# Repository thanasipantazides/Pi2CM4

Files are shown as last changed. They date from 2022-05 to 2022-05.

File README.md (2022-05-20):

# Pi2CM4
An adapter board for the [Raspberry Pi Compute Module 4](https://datasheets.raspberrypi.com/cm4/cm4-datasheet.pdf) that has the footprint and I/O connectors of a Raspberry Pi 2/3/[4](https://datasheets.raspberrypi.com/rpi4/raspberry-pi-4-product-brief.pdf).

## WARNING: HAS NOT BEEN TESTED.
I will update when testing is done.

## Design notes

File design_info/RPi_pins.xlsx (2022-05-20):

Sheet: CM4_pins
Pin | Function
1 | GND
2 | GND
3 | Ethernet_Pair3_P
4 | Ethernet_Pair1_P
5 | Ethernet_Pair3_N
6 | Ethernet_Pair1_N
7 | GND
8 | GND
9 | Ethernet_Pair2_N
10 | Ethernet_Pair0_N
11 | Ethernet_Pair2_P
12 | Ethernet_Pair0_P
13 | GND
14 | GND
15 | Ethernet_nLED3
16 | Ethernet_SYNC_IN
17 | Ethernet_nLED2
18 | Ethernet_SYNC_OUT
19 | Ethernet_nLED1
20 | EEPROM_nWP
21 | Pi_nLED_Activity
22 | GND
23 | GND
24 | GPIO26
25 | GPIO21
26 | GPIO19
27 | GPIO20
28 | GPIO13
29 | GPIO16
30 | GPIO6
31 | GPIO12
32 | GND
33 | GND
34 | GPIO5
35 | ID_SC
36 | ID_SD
37 | GPIO7
38 | GPIO11
39 | GPIO8
40 | GPIO9
41 | GPIO25
42 | GND
43 | GND
44 | GPIO10
45 | GPIO24
46 | GPIO22
47 | GPIO23
48 | GPIO27
49 | GPIO18
50 | GPIO17
51 | GPIO15
52 | GND
53 | GND
54 | GPIO4
55 | GPIO14
56 | GPIO3
57 | SD_CLK
58 | GPIO2
59 | GND
60 | GND
61 | SD_DAT3
62 | SD_CMD
63 | SD_DAT0
64 | SD_DAT5
65 | GND
66 | GND
67 | SD_DAT1
68 | SD_DAT4
69 | SD_DAT2
70 | SD_DAT7
71 | GND
72 | SD_DAT6
73 | SD_VDD_Override
74 | GND
75 | SD_PWR_ON
76 | Reserved
77 | 5V_IN
78 | GPIO_VREF
79 | 5V_IN
80 | SCL0
81 | 5V_IN
82 | SDA0
83 | 5V_IN
84 | CM4_3.3V_OUT
85 | 5V_IN
86 | CM4_3.3V_OUT
87 | 5V_IN
88 | CM4_1.8V_OUT
89 | WL_nDisable
90 | CM4_1.8V_OUT
91 | BT_nDisable
92 | RUN_PG
93 | nRPIBOOT
94 | AnalogIP1
95 | Pi_LED_nPWR
96 | AnalogIP0
97 | Camera_GPIO
98 | GND
99 | GLOBAL_EN
100 | nEXTRST
101 | USB_OTG_ID
102 | PCIe_CLK_nREQ
103 | USB_N
104 | DNC
105 | USB_P
106 | DNC
107 | GND
108 | GND
109 | PCIe_nRST
110 | PCIe_CLK_P
111 | VDAC_COMP
112 | PCIe_CLK_N
113 | GND
114 | GND
115 | CAM1_D0_N
116 | PCIe_RX_P
117 | CAM1_D0_P
118 | PCIe_RX_N
119 | GND
120 | GND
121 | CAM1_D1_N
122 | PCIe_TX_P
123 | CAM1_D1_P
124 | PCIe_TX_N
125 | GND
126 | GND
127 | CAM1_C_N
128 | CAM0_D0_N
129 | CAM1_C_P
130 | CAM0_D0_P
131 | GND
132 | GND
133 | CAM1_D2_N
134 | CAM0_D1_N
135 | CAM1_D2_P
136 | CAM0_D1_P
137 | GND
138 | GND
139 | CAM1_D3_N
140 | CAM0_C_N
141 | CAM1_D3_P
142 | CAM0_C_P
143 | HDMI1_HOTPLUG
144 | GND
145 | HDMI1_SDA
146 | HDMI1_TX2_P
147 | HDMI1_SCL
148 | HDMI1_TX2_N
149 | HDMI1_CEC
150 | GND
151 | HDMI0_CEC
152 | HDMI1_TX1_P
153 | HDMI0_HOTPLUG
154 | HDMI1_TX1_N
155 | GND
156 | GND
157 | DSI0_D0_N
158 | HDMI1_TX0_P
159 | DSI0_D0_P
160 | HDMI1_TX0_N
161 | GND
162 | GND
163 | DSI0_D1_N
164 | HDMI1_CLK_P
165 | DSI0_D1_P
166 | HDMI1_CLK_N
167 | GND
168 | GND
169 | DSI0_C_N
170 | HDMI0_TX2_P
171 | DSI0_C_P
172 | HDMI0_TX2_N
173 | GND
174 | GND
175 | DSI1_D0_N
176 | HDMI0_TX1_P
177 | DSI1_D0_P
178 | HDMI0_TX1_N
179 | GND
180 | GND
181 | DSI1_D1_N
182 | HDMI0_TX0_P
183 | DSI1_D1_P
184 | HDMI0_tx0_N
185 | GND
186 | GND
187 | DSI1_C_N
188 | HDMI0_CLK_P
189 | DSI1_C_P
190 | HDMI0_CLK_N
191 | GND
192 | GND
193 | DSI1_D2_N
194 | DSI1_D3_N
195 | DSI1_D2_P
196 | DSI1_D3_P
197 | GND
198 | GND
199 | HDMI0_SDA
200 | HDMI0_SCL

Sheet: Pi4_pins
Pin | Function
1 | 3.3V_IN
2 | 5V_IN
3 | GPIO2
4 | 5V_IN
5 | GPIO3
6 | GND
7 | GPIO4
8 | GPIO14
9 | GND
10 | GPIO15
11 | GPIO17
12 | GPIO18
13 | GPIO27
14 | GND
15 | GPIO22
16 | GPIO23
17 | 3.3V_IN
18 | GPIO24
19 | GPIO10
20 | GND
21 | GPIO9
22 | GPIO25
23 | GPIO11
24 | GPIO8
25 | GND
26 | GPIO7
27 | ID_SD
28 | ID_SC
29 | GPIO5
30 | GND
31 | GPIO6
32 | GPIO12
33 | GPIO13
34 | GND
35 | GPIO19
36 | GPIO16
37 | GPIO26
38 | GPIO20
39 | GND
40 | GPIO21

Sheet: CM4_GPIOs
GPIO | Pull | Alt0 | Alt1 | Alt2 | Alt3 | Alt4 | Alt5

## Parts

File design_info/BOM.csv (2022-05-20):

Id | Designator | Package | Quantity | Designation | Supplier and ref
1 | Module1 | Raspberry-Pi-4-Compute-Module | 1 | ComputeModule4
2 | J11 | USB_Micro-B_EDAC_UCON00686 | 1 | USB_OTG
3 | R15,R7 | R_0402_1005Metric | 2 | 12K 1%
4 | J14,J6 | Molex_052610-1572_2x15-1MP_P1.0mm_Vertical | 2 | Conn_02x15_Counter_Clockwise
5 | R4,R3 | R_0402_1005Metric | 2 | 1k
6 | C4,C3 | C_0402_1005Metric | 2 | 27pF
7 | J2,J1 | HDMI_Micro-D_Molex_46765-1x01 | 2 | 0467651001
8 | C9,C20,C10,C11,C12,C8,C21,C7,C2 | C_0402_1005Metric | 9 | 100n
9 | R13,R12,R16,R14 | R_0402_1005Metric | 4 | 36K 1%
10 | R19,R23,R22 | R_0402_1005Metric | 3 | 4.7k
11 | U6 | MSOP-10_3x3mm_P0.5mm | 1 | FSUSB42MUX
12 | TP2,TP1 | TestPoint_Pad_2.0x2.0mm | 2 | TestPoint
13 | H4 | MountingHole_2.7mm_M2.5 | 1 | hole
14 | C18,C15,C5,C16,C17,C13,C6,C1,C19 | C_0805_2012Metric | 9 | 10u
15 | D4,D3 | D_SOD-123 | 2 | D_Zener
16 | U5 | TRJG0926HENL | 1 | MagJack-A70-112-331N126
17 | U8,U3,U4 | USON-10_2.5x1.0mm_P0.5mm | 3 | TPD4EUSB30
18 | Y1 | Crystal_SMD_2520-4Pin_2.5x2.0mm | 1 | Crystal_GND24_Small
19 | R18,R21,R20 | R_0402_1005Metric | 3 | 2
20 | H3,H2,H1 | MountingHole_2.7mm_M2.5 | 3 | MountingHole
21 | J12,J4 | MOLEX_USB_67298-4090 | 2 | 690-008-221-904
22 | J3 | PinHeader_1x02_P2.54mm_Vertical | 1 | Conn_01x02
23 | J13 | PinSocket_1x02_P2.54mm_Vertical | 1 | Conn_01x02
24 | C14 | C_1210_3225Metric | 1 | 100uF
25 | R2,R1,R11,R10 | R_0402_1005Metric | 4 | 2.2K 1%
26 | D1 | LED_0603_1608Metric | 1 | LED Green
27 | D2 | LED_0603_1608Metric | 1 | LED Red
28 | J7,J5 | PinSocket_2x02_P2.54mm_Vertical | 2 | Conn_02x02_Odd_Even
29 | U7 | QFN-36-1EP_6x6mm_P0.5mm_EP3.7x3.7mm | 1 | USB2514B-I/M2
30 | U1 | SOT-353_SC-70-5 | 1 | 74LVC1G07SE-7
31 | J9 | PinHeader_2x20_P2.54mm_Vertical | 1 | header
32 | U9 | SOT-23-6 | 1 | AP22653W6
33 | U11 | SOT-23 | 1 | RT9742SNGV
34 | R17 | R_0402_1005Metric | 1 | 15K 1%
35 | R8,R9 | R_0402_1005Metric | 2 | 470R
36 | D6,D5 | D_MELF | 2 | D
37 | U2 | SOT-23-5 | 1 | RT9742GGJ5
38 | R5,R6 | R_0402_1005Metric | 2 | nf
39 | U10 | SOT-23-5 | 1 | 74LVC1G04
40 | Q1 | PowerPAK_1212_Dual | 1 | Q_Dual_PMOS_S1G1S2G2D2D2D1D1
41 | J8 | SDCARD_MOLEX_503398-1892 | 1 | Micro_SD_Card_Det

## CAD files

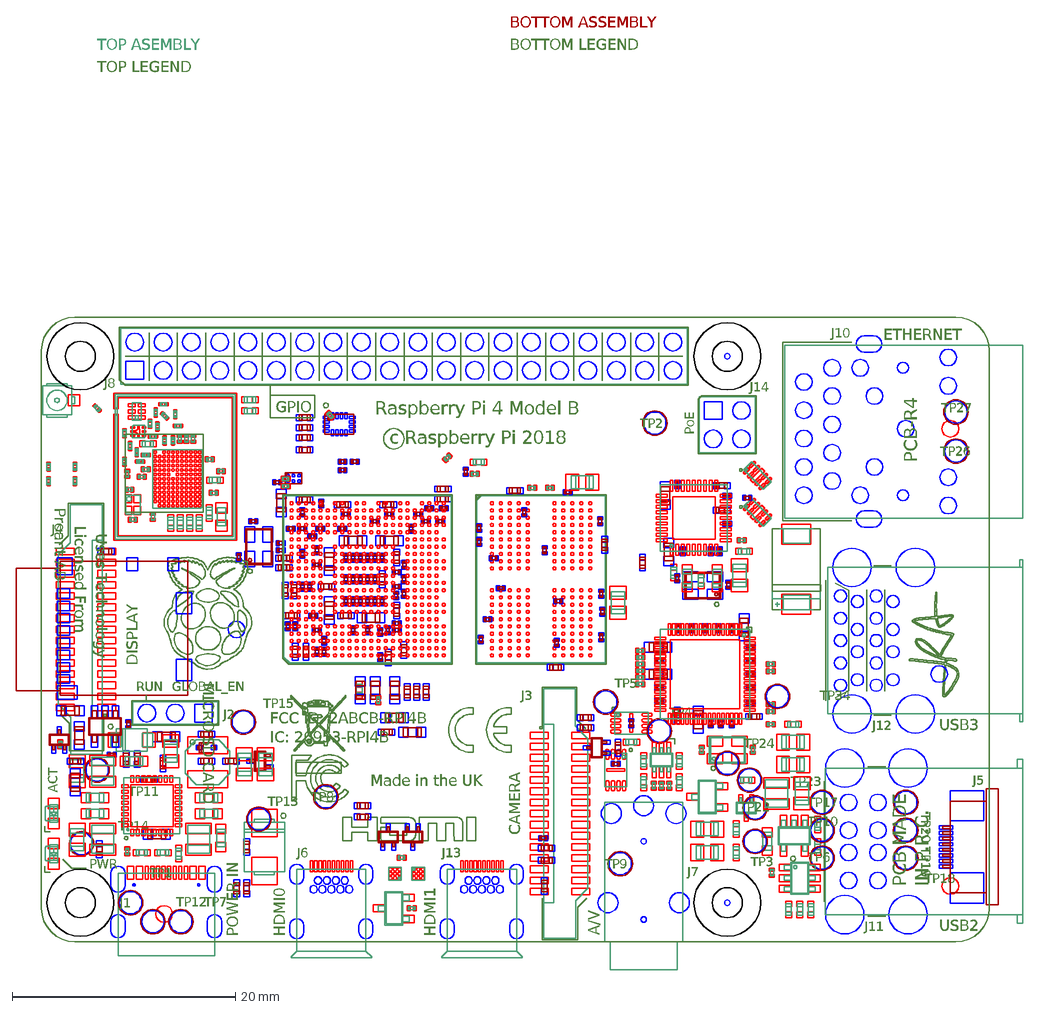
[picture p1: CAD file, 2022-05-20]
design_info/raspberry-pi-4-mechanical-drawing.dxf
TP20
TP19
TP18
TP17
TP10
TP6
TP5
TP34
TP15
TP14
TP13
TP11
TP8
TP7
TP24
TP23
TP22
TP12
TP9
TP4
TP3
TP2
TP1
TP27
TP26
J5
Made in the UK
IN P.R.C.
PCB MADE
IC: 20953-RPI4B
FCC ID: 2ABCB-RPI4B
PCB-R4
RUN
GLOBAL_EN
Proant AB
Licensed From
Uses Technology
MICRO SD CARD
GPIO
c Raspberry Pi 2018
Raspberry Pi 4 Model B
J2
J8
J14
J11
J12
J10
J7
J13
J3
J6
J1
J4
PoE
USB3
USB2
ETHERNET
A/V
DISPLAY
CAMERA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

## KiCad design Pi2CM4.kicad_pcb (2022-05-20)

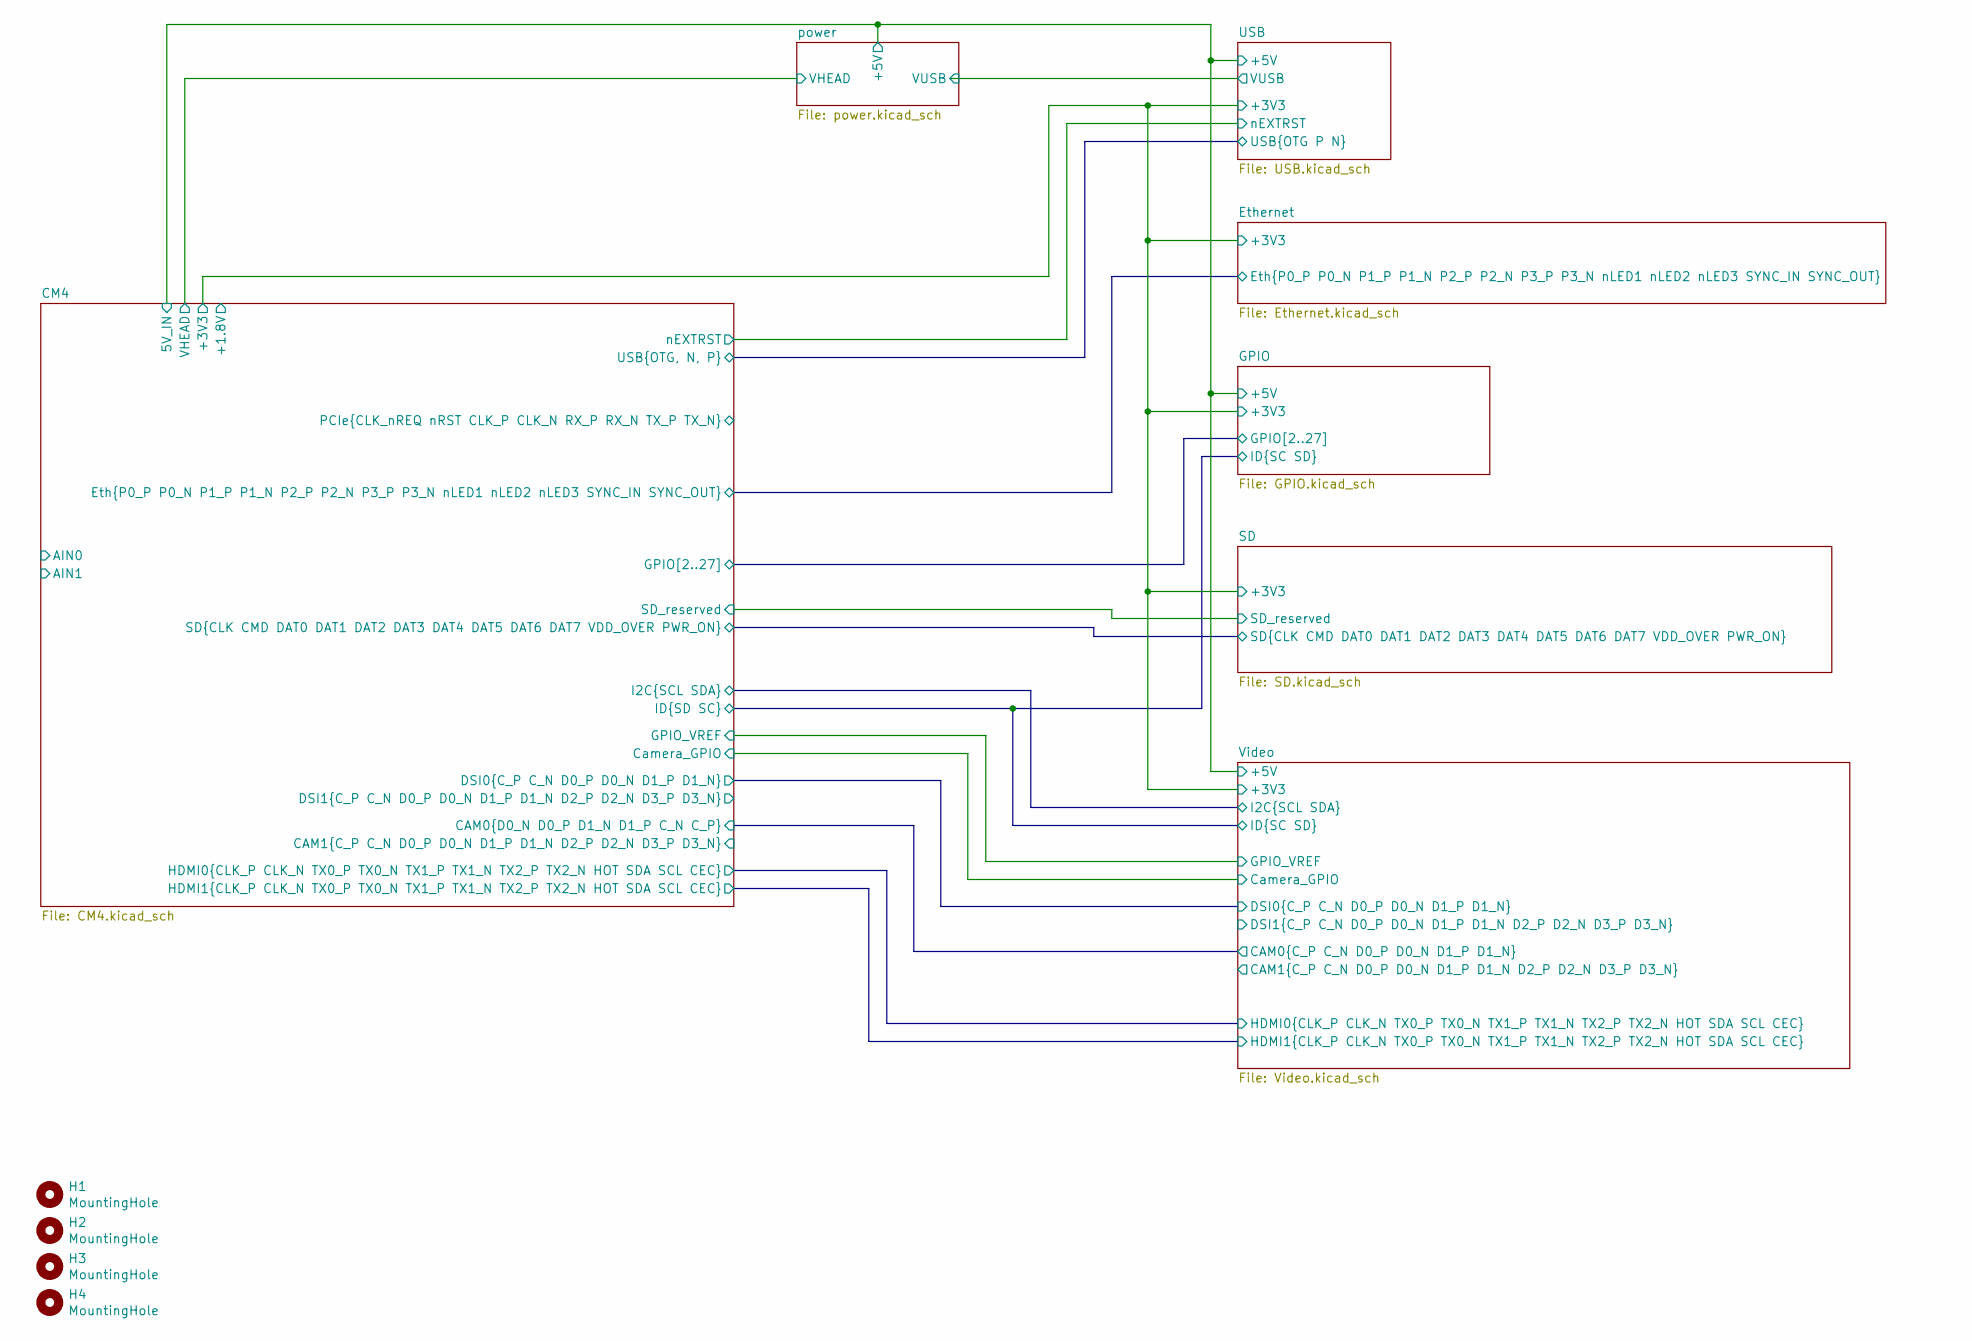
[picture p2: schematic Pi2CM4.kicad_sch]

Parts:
H1, H2, H3, H4: MountingHole; MountingHole_2.7mm_M2.5; Part Description M2.5 mounting hole

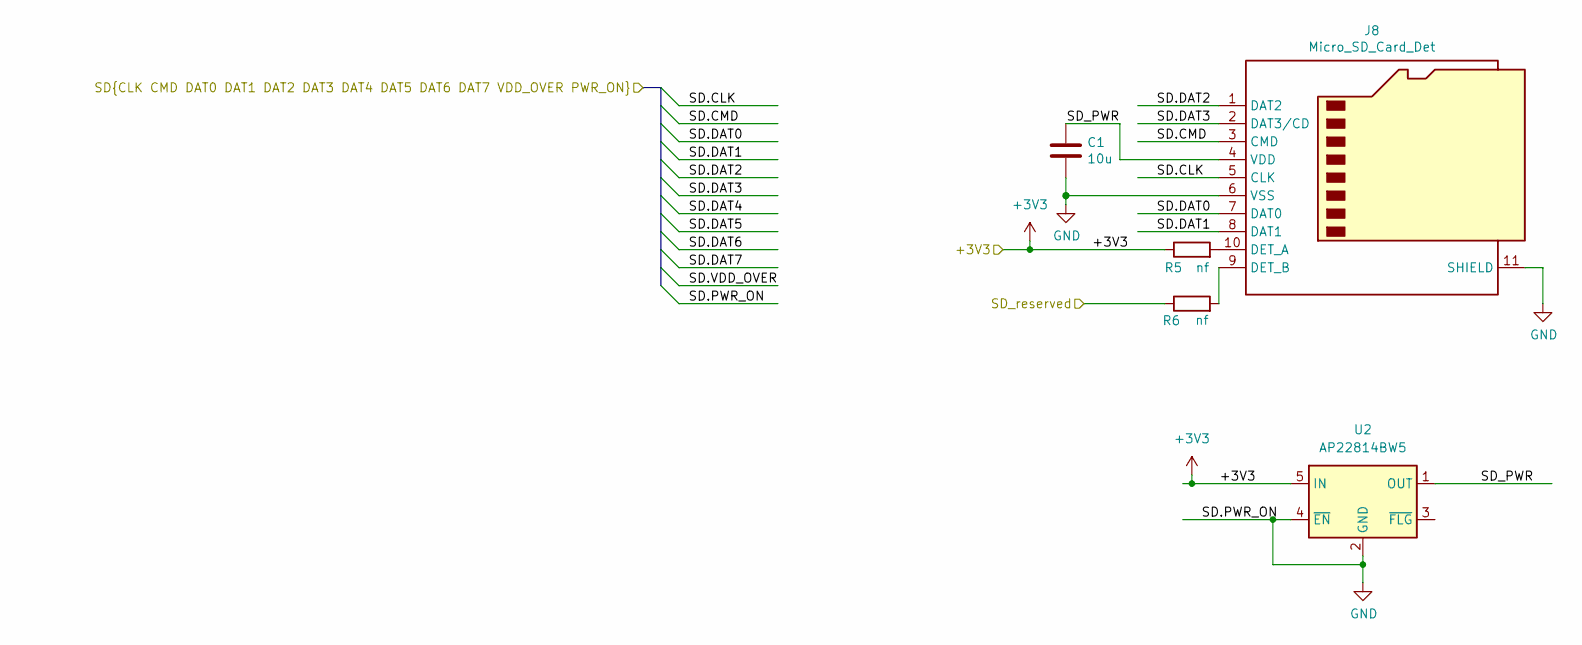
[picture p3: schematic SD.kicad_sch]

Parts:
C1: 10u; C_0805_2012Metric; Part Description 10uF 10% 10V Ceramic Capacitor X7R 0805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
J8: Micro_SD_Card_Det; SDCARD_MOLEX_503398-1892; Part Description 9 (8 + 1) Position Card Connector micro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
R5, R6: nf; R_0402_1005Metric; Part Description Resistor 1K M1005 1% 63mW
U2: AP22814BW5; SOT-23-5

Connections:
+3V3: R5.1, U2.5 (IN); also elsewhere on the board
/CM4/SD.CLK: J8.5 (CLK); also elsewhere on the board
/CM4/SD.CMD: J8.3 (CMD); also elsewhere on the board
/CM4/SD.DAT0: J8.7 (DAT0); also elsewhere on the board
/CM4/SD.DAT1: J8.8 (DAT1); also elsewhere on the board
/CM4/SD.DAT2: J8.1 (DAT2); also elsewhere on the board
/CM4/SD.DAT3: J8.2 (DAT3/CD); also elsewhere on the board
/CM4/SD_reserved: R6.1; also elsewhere on the board
/SD/SD_PWR: C1.1, J8.4 (VDD), U2.1 (OUT)
GND: C1.2, J8.6 (VSS), J8.11 (SHIELD), U2.2 (GND), U2.4 (~EN); also elsewhere on the board
unnamed: J8.9 (DET_B), R6.2
unnamed: J8.10 (DET_A), R5.2

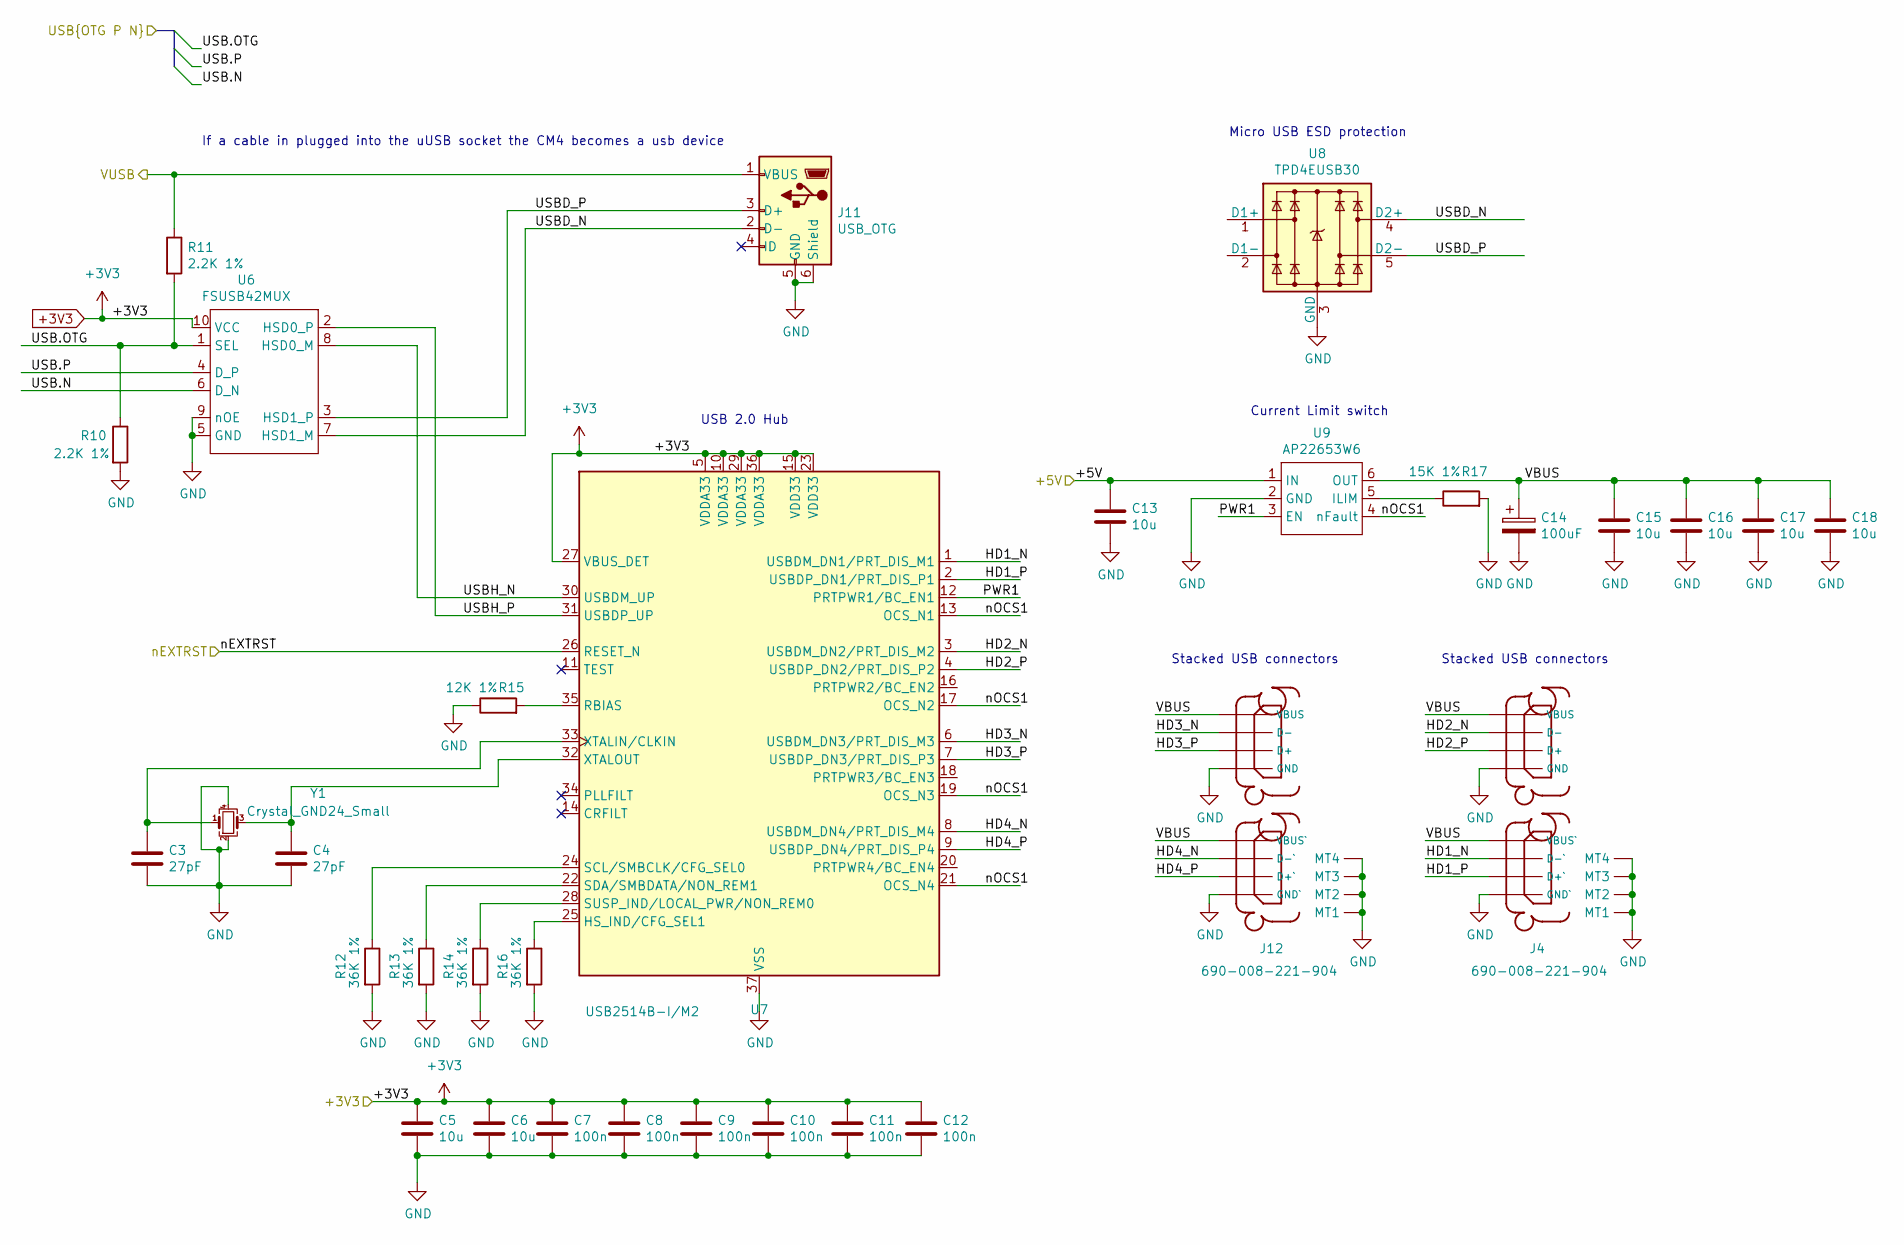
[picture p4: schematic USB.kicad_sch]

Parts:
C3, C4: 27pF; C_0402_1005Metric; Part Description 27pF 5% 50V Ceramic Capacitor C0G, NP0 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
C5, C6, C13, C15, C16, C17, C18: 10u; C_0805_2012Metric; Part Description 10uF 10% 10V Ceramic Capacitor X7R 0805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
C7, C8, C9, C10, C11, C12: 100n; C_0402_1005Metric; Part Description 0.1uF 10% 16V Ceramic Capacitor X7R 040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
C14: 100uF; C_1210_3225Metric; Part Description Capacitor, SP-Cap, 100u, 6.3V, 15mR ESR
J4, J12: 690-008-221-904; MOLEX_USB_67298-4090; Part Description USB-A (USB TYPE-A), Stacked Receptacle 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
J11: USB_OTG; USB_Micro-B_EDAC_UCON00686; Part Description USB - micro B USB 2.0 Receptacle Connec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
R10, R11: 2.2K 1%; R_0402_1005Metric; Part Description Resistor 2.2K M1005 1% 63mW
R12, R13, R14, R16: 36K 1%; R_0402_1005Metric; Part Description Resistor 36K M1005 1% 63mW
R15: 12K 1%; R_0402_1005Metric; Part Description Resistor 12K M1005 1% 63mW
R17: 15K 1%; R_0402_1005Metric; Part Description Resistor 15K M1005 1% 63mW
U6: FSUSB42MUX; Texas_R-PUQFN-N10; Part Description USB Switch IC 1 Channel 10-MSOP
U7: USB2514B-I/M2; QFN-36-1EP_6x6mm_P0.5mm_EP3.7x3.7mm; Part Description USB Hub Controller USB Interface 36-SQF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
U8: TPD4EUSB30; USON-10_2.5x1.0mm_P0.5mm; Part Description Quad TVS diode for high speed signals (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
U9: AP22653W6; SOT-23-6; Part Description Power Switch/Driver 1:1 P-Channel 2.1A 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
Y1: Crystal_GND24_Small; Crystal_SMD_2520-4Pin_2.5x2.0mm

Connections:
+3V3: C5.1, C6.1, C7.1, C8.1, C9.1, C10.1, C11.1, C12.1, U6.10 (VCC), U7.5 (VDDA33), U7.10 (VDDA33), U7.15 (VDD33), U7.23 (VDD33), U7.27 (VBUS_DET), U7.29 (VDDA33), U7.36 (VDDA33); also elsewhere on the board
+5V: C13.1, U9.1 (IN); also elsewhere on the board
/CM4/USB.N: U6.6 (D_N); also elsewhere on the board
/CM4/USB.OTG: R10.1, R11.2, U6.1 (SEL); also elsewhere on the board
/CM4/USB.P: U6.4 (D_P); also elsewhere on the board
/CM4/nEXTRST: U7.26 (RESET_N); also elsewhere on the board
/USB/HD1_N: J4.2 (D-`), U7.1 (USBDM_DN1/PRT_DIS_M1)
/USB/HD1_P: J4.3 (D+`), U7.2 (USBDP_DN1/PRT_DIS_P1)
/USB/HD2_N: J4.6 (D-), U7.3 (USBDM_DN2/PRT_DIS_M2)
/USB/HD2_P: J4.7 (D+), U7.4 (USBDP_DN2/PRT_DIS_P2)
/USB/HD3_N: J12.6 (D-), U7.6 (USBDM_DN3/PRT_DIS_M3)
/USB/HD3_P: J12.7 (D+), U7.7 (USBDP_DN3/PRT_DIS_P3)
/USB/HD4_N: J12.2 (D-`), U7.8 (USBDM_DN4/PRT_DIS_M4)
/USB/HD4_P: J12.3 (D+`), U7.9 (USBDP_DN4/PRT_DIS_P4)
/USB/PWR1: U7.12 (PRTPWR1/BC_EN1), U9.3 (EN)
/USB/USBD_N: J11.2 (D-), U6.7 (HSD1_M), U8.4 (D2+), U8.7
/USB/USBD_P: J11.3 (D+), U6.3 (HSD1_P), U8.5 (D2-), U8.6
/USB/USBH_N: U6.8 (HSD0_M), U7.30 (USBDM_UP)
/USB/USBH_P: U6.2 (HSD0_P), U7.31 (USBDP_UP)
/USB/VBUS: C14.1, C15.1, C16.1, C17.1, C18.1, J4.1 (VBUS`), J4.5 (VBUS), J12.1 (VBUS`), J12.5 (VBUS), U9.6 (OUT)
/USB/VUSB: J11.1 (VBUS), R11.1
/USB/nOCS1: U7.13 (OCS_N1), U7.17 (OCS_N2), U7.19 (OCS_N3), U7.21 (OCS_N4), U9.4 (nFault)
GND: C3.2, C4.2, C5.2, C6.2, C7.2, C8.2, C9.2, C10.2, C11.2, C12.2, C13.2, C14.2, C15.2, C16.2, C17.2, C18.2, J4.4 (GND`), J4.8 (GND), J4.MT1, J4.MT2, J4.MT3, J4.MT4, J11.5 (GND), J11.6 (Shield), J12.4 (GND`), J12.8 (GND), J12.MT1, J12.MT2, J12.MT3, J12.MT4, R10.2, R12.2, R13.2, R14.2, R15.1, R16.2, R17.2, U6.5 (GND), U6.9 (nOE), U7.37 (VSS), U8.3 (GND), U8.8 (GND), U9.2 (GND), Y1.2, Y1.4; also elsewhere on the board
unnamed: C3.1, U7.33 (XTALIN/CLKIN), Y1.1
unnamed: C4.1, U7.32 (XTALOUT), Y1.3
unnamed: R12.1, U7.24 (SCL/SMBCLK/CFG_SEL0)
unnamed: R13.1, U7.22 (SDA/SMBDATA/NON_REM1)
unnamed: R14.1, U7.28 (SUSP_IND/LOCAL_PWR/NON_REM0)
unnamed: R15.2, U7.35 (RBIAS)
unnamed: R16.1, U7.25 (HS_IND/CFG_SEL1)
unnamed: R17.1, U9.5 (ILIM)
unnamed: U8.1 (D1+), U8.10
unnamed: U8.2 (D1-), U8.9

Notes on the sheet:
Current Limit switch
Stacked USB connectors
Micro USB ESD protection
If a cable in plugged into the uUSB socket the CM4 becomes a usb device
USB 2.0 Hub

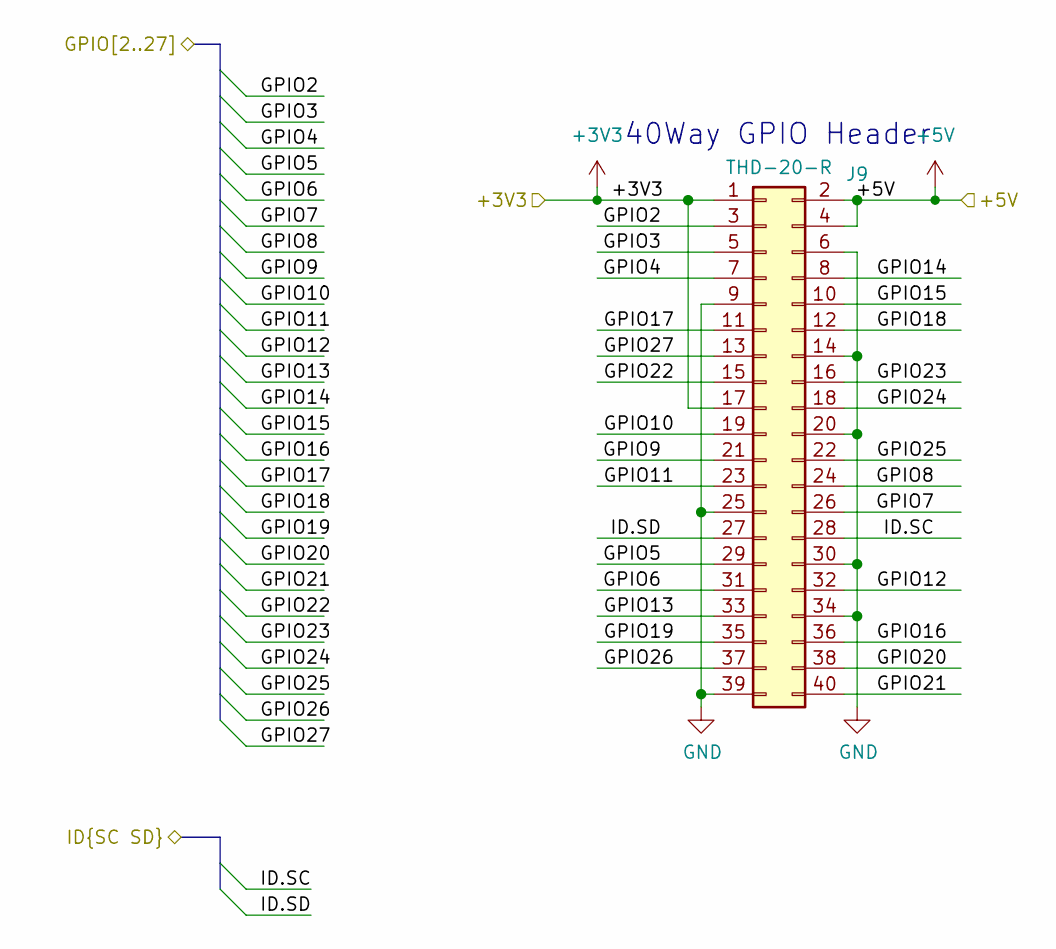
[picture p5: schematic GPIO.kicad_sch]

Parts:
J9: THD-20-R; PinHeader_2x20_P2.54mm_Vertical; Part Description PinHeader_2x20_P2.54mm_Vertical

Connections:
+3V3: J9.1, J9.17; also elsewhere on the board
+5V: J9.2, J9.4; also elsewhere on the board
/CM4/GPIO2: J9.3; also elsewhere on the board
/CM4/GPIO3: J9.5; also elsewhere on the board
/CM4/GPIO4: J9.7; also elsewhere on the board
/CM4/GPIO5: J9.29; also elsewhere on the board
/CM4/GPIO6: J9.31; also elsewhere on the board
/CM4/GPIO7: J9.26; also elsewhere on the board
/CM4/GPIO8: J9.24; also elsewhere on the board
/CM4/GPIO9: J9.21; also elsewhere on the board
/CM4/GPIO10: J9.19; also elsewhere on the board
/CM4/GPIO11: J9.23; also elsewhere on the board
/CM4/GPIO12: J9.32; also elsewhere on the board
/CM4/GPIO13: J9.33; also elsewhere on the board
/CM4/GPIO14: J9.8; also elsewhere on the board
/CM4/GPIO15: J9.10; also elsewhere on the board
/CM4/GPIO16: J9.36; also elsewhere on the board
/CM4/GPIO17: J9.11; also elsewhere on the board
/CM4/GPIO18: J9.12; also elsewhere on the board
/CM4/GPIO19: J9.35; also elsewhere on the board
/CM4/GPIO20: J9.38; also elsewhere on the board
/CM4/GPIO21: J9.40; also elsewhere on the board
/CM4/GPIO22: J9.15; also elsewhere on the board
/CM4/GPIO23: J9.16; also elsewhere on the board
/CM4/GPIO24: J9.18; also elsewhere on the board
/CM4/GPIO25: J9.22; also elsewhere on the board
/CM4/GPIO26: J9.37; also elsewhere on the board
/CM4/GPIO27: J9.13; also elsewhere on the board
/CM4/ID.SC: J9.28; also elsewhere on the board
/CM4/ID.SD: J9.27; also elsewhere on the board
GND: J9.6, J9.9, J9.14, J9.20, J9.25, J9.30, J9.34, J9.39; also elsewhere on the board

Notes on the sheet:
40Way GPIO Header

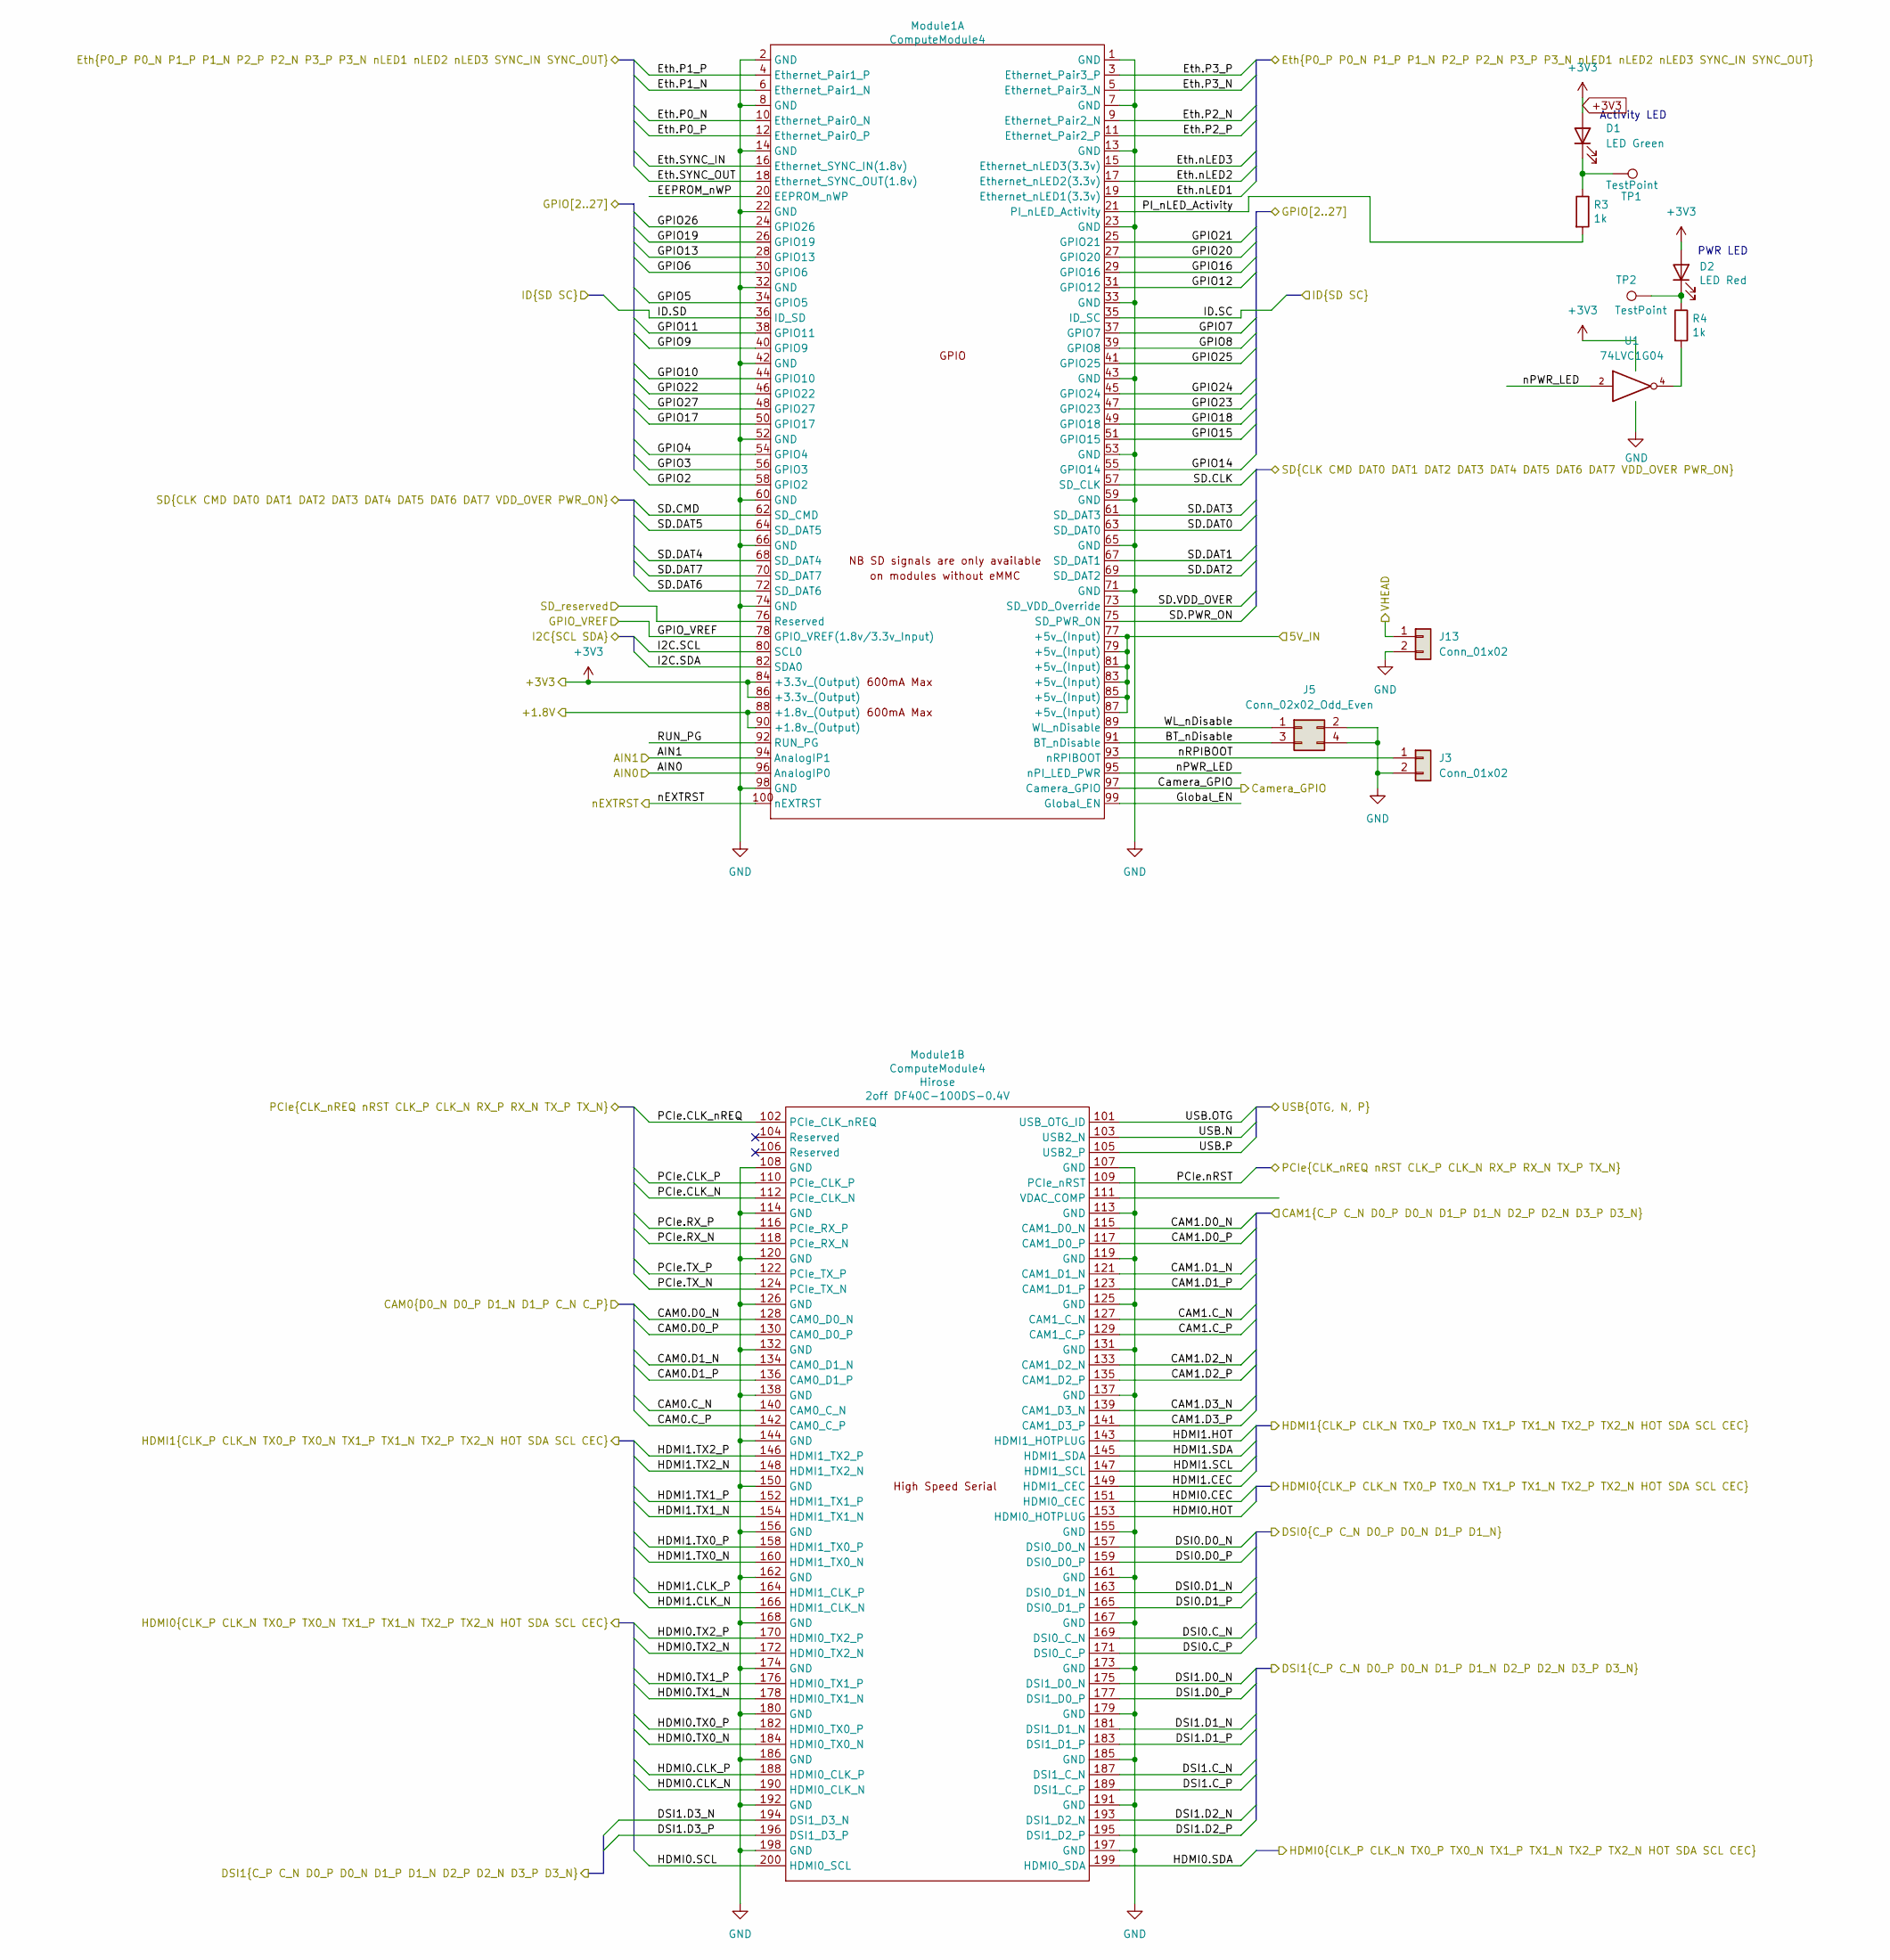
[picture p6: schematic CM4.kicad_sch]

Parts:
D1: LED Green; LED_0603_1608Metric; Part Description Green 572nm LED Indication - Discrete 2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
D2: LED Red; LED_0603_1608Metric; Part Description Red 620nm LED Indication - Discrete 2.2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
J3: Conn_01x02; PinHeader_1x02_P2.54mm_Vertical
J5: Conn_02x02_Odd_Even; PinSocket_2x02_P2.54mm_Vertical
J13: Conn_01x02; PinSocket_1x02_P2.54mm_Vertical
Module1: ComputeModule4; Raspberry-Pi-4-Compute-Module; Part Description 100 Position Connector Receptacle, Cent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
R3, R4: 1k; R_0402_1005Metric; Part Description Resistor 1K M1005 1% 63mW
TP1, TP2: TestPoint; TestPoint_Pad_2.0x2.0mm
U1: 74LVC1G04; SOT-23-5

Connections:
+3V3: D1.2 (A), D2.2 (A), Module1.84 (+3.3v_(Output)), Module1.86 (+3.3v_(Output)), U1.5 (VCC); also elsewhere on the board
+5V: Module1.77 (+5v_(Input)), Module1.79 (+5v_(Input)), Module1.81 (+5v_(Input)), Module1.83 (+5v_(Input)), Module1.85 (+5v_(Input)), Module1.87 (+5v_(Input)); also elsewhere on the board
/CM4/+1.8V: Module1.88 (+1.8v_(Output)), Module1.90 (+1.8v_(Output))
/CM4/AIN0: Module1.96 (AnalogIP0)
/CM4/AIN1: Module1.94 (AnalogIP1)
/CM4/BT_nDisable: J5.3, Module1.91 (BT_nDisable)
/CM4/CAM0.C_N: Module1.140 (CAM0_C_N); also elsewhere on the board
/CM4/CAM0.C_P: Module1.142 (CAM0_C_P); also elsewhere on the board
/CM4/CAM0.D0_N: Module1.128 (CAM0_D0_N); also elsewhere on the board
/CM4/CAM0.D0_P: Module1.130 (CAM0_D0_P); also elsewhere on the board
/CM4/CAM0.D1_N: Module1.134 (CAM0_D1_N); also elsewhere on the board
/CM4/CAM0.D1_P: Module1.136 (CAM0_D1_P); also elsewhere on the board
/CM4/CAM1.C_N: Module1.127 (CAM1_C_N)
/CM4/CAM1.C_P: Module1.129 (CAM1_C_P)
/CM4/CAM1.D0_N: Module1.115 (CAM1_D0_N)
/CM4/CAM1.D0_P: Module1.117 (CAM1_D0_P)
/CM4/CAM1.D1_N: Module1.121 (CAM1_D1_N)
/CM4/CAM1.D1_P: Module1.123 (CAM1_D1_P)
/CM4/CAM1.D2_N: Module1.133 (CAM1_D2_N)
/CM4/CAM1.D2_P: Module1.135 (CAM1_D2_P)
/CM4/CAM1.D3_N: Module1.139 (CAM1_D3_N)
/CM4/CAM1.D3_P: Module1.141 (CAM1_D3_P)
/CM4/Camera_GPIO: Module1.97 (Camera_GPIO); also elsewhere on the board
/CM4/DSI0.C_N: Module1.169 (DSI0_C_N); also elsewhere on the board
/CM4/DSI0.C_P: Module1.171 (DSI0_C_P); also elsewhere on the board
/CM4/DSI0.D0_N: Module1.157 (DSI0_D0_N); also elsewhere on the board
/CM4/DSI0.D0_P: Module1.159 (DSI0_D0_P); also elsewhere on the board
/CM4/DSI0.D1_N: Module1.163 (DSI0_D1_N); also elsewhere on the board
/CM4/DSI0.D1_P: Module1.165 (DSI0_D1_P); also elsewhere on the board
/CM4/DSI1.C_N: Module1.187 (DSI1_C_N)
/CM4/DSI1.C_P: Module1.189 (DSI1_C_P)
/CM4/DSI1.D0_N: Module1.175 (DSI1_D0_N)
/CM4/DSI1.D0_P: Module1.177 (DSI1_D0_P)
/CM4/DSI1.D1_N: Module1.181 (DSI1_D1_N)
/CM4/DSI1.D1_P: Module1.183 (DSI1_D1_P)
/CM4/DSI1.D2_N: Module1.193 (DSI1_D2_N)
/CM4/DSI1.D2_P: Module1.195 (DSI1_D2_P)
/CM4/DSI1.D3_N: Module1.194 (DSI1_D3_N)
/CM4/DSI1.D3_P: Module1.196 (DSI1_D3_P)
/CM4/EEPROM_nWP: Module1.20 (EEPROM_nWP)
/CM4/Eth.P0_N: Module1.10 (Ethernet_Pair0_N); also elsewhere on the board
/CM4/Eth.P0_P: Module1.12 (Ethernet_Pair0_P); also elsewhere on the board
/CM4/Eth.P1_N: Module1.6 (Ethernet_Pair1_N); also elsewhere on the board
/CM4/Eth.P1_P: Module1.4 (Ethernet_Pair1_P); also elsewhere on the board
/CM4/Eth.P2_N: Module1.9 (Ethernet_Pair2_N); also elsewhere on the board
/CM4/Eth.P2_P: Module1.11 (Ethernet_Pair2_P); also elsewhere on the board
/CM4/Eth.P3_N: Module1.5 (Ethernet_Pair3_N); also elsewhere on the board
/CM4/Eth.P3_P: Module1.3 (Ethernet_Pair3_P); also elsewhere on the board
/CM4/Eth.SYNC_IN: Module1.16 (Ethernet_SYNC_IN(1.8v))
/CM4/Eth.SYNC_OUT: Module1.18 (Ethernet_SYNC_OUT(1.8v))
/CM4/Eth.nLED1: Module1.19 (Ethernet_nLED1(3.3v))
/CM4/Eth.nLED2: Module1.17 (Ethernet_nLED2(3.3v)); also elsewhere on the board
/CM4/Eth.nLED3: Module1.15 (Ethernet_nLED3(3.3v)); also elsewhere on the board
/CM4/GPIO2: Module1.58 (GPIO2); also elsewhere on the board
/CM4/GPIO3: Module1.56 (GPIO3); also elsewhere on the board
/CM4/GPIO4: Module1.54 (GPIO4); also elsewhere on the board
/CM4/GPIO5: Module1.34 (GPIO5); also elsewhere on the board
/CM4/GPIO6: Module1.30 (GPIO6); also elsewhere on the board
/CM4/GPIO7: Module1.37 (GPIO7); also elsewhere on the board
/CM4/GPIO8: Module1.39 (GPIO8); also elsewhere on the board
/CM4/GPIO9: Module1.40 (GPIO9); also elsewhere on the board
/CM4/GPIO10: Module1.44 (GPIO10); also elsewhere on the board
/CM4/GPIO11: Module1.38 (GPIO11); also elsewhere on the board
/CM4/GPIO12: Module1.31 (GPIO12); also elsewhere on the board
/CM4/GPIO13: Module1.28 (GPIO13); also elsewhere on the board
/CM4/GPIO14: Module1.55 (GPIO14); also elsewhere on the board
/CM4/GPIO15: Module1.51 (GPIO15); also elsewhere on the board
/CM4/GPIO16: Module1.29 (GPIO16); also elsewhere on the board
/CM4/GPIO17: Module1.50 (GPIO17); also elsewhere on the board
/CM4/GPIO18: Module1.49 (GPIO18); also elsewhere on the board
/CM4/GPIO19: Module1.26 (GPIO19); also elsewhere on the board
/CM4/GPIO20: Module1.27 (GPIO20); also elsewhere on the board
/CM4/GPIO21: Module1.25 (GPIO21); also elsewhere on the board
/CM4/GPIO22: Module1.46 (GPIO22); also elsewhere on the board
/CM4/GPIO23: Module1.47 (GPIO23); also elsewhere on the board
/CM4/GPIO24: Module1.45 (GPIO24); also elsewhere on the board
/CM4/GPIO25: Module1.41 (GPIO25); also elsewhere on the board
/CM4/GPIO26: Module1.24 (GPIO26); also elsewhere on the board
/CM4/GPIO27: Module1.48 (GPIO27); also elsewhere on the board
/CM4/GPIO_VREF: Module1.78 (GPIO_VREF(1.8v/3.3v_Input)); also elsewhere on the board
/CM4/Global_EN: Module1.99 (Global_EN)
/CM4/HDMI0.CEC: Module1.151 (HDMI0_CEC); also elsewhere on the board
/CM4/HDMI0.CLK_N: Module1.190 (HDMI0_CLK_N); also elsewhere on the board
/CM4/HDMI0.CLK_P: Module1.188 (HDMI0_CLK_P); also elsewhere on the board
/CM4/HDMI0.HOT: Module1.153 (HDMI0_HOTPLUG); also elsewhere on the board
/CM4/HDMI0.SCL: Module1.200 (HDMI0_SCL); also elsewhere on the board
/CM4/HDMI0.SDA: Module1.199 (HDMI0_SDA); also elsewhere on the board
/CM4/HDMI0.TX0_N: Module1.184 (HDMI0_TX0_N); also elsewhere on the board
/CM4/HDMI0.TX0_P: Module1.182 (HDMI0_TX0_P); also elsewhere on the board
/CM4/HDMI0.TX1_N: Module1.178 (HDMI0_TX1_N); also elsewhere on the board
/CM4/HDMI0.TX1_P: Module1.176 (HDMI0_TX1_P); also elsewhere on the board
/CM4/HDMI0.TX2_N: Module1.172 (HDMI0_TX2_N); also elsewhere on the board
/CM4/HDMI0.TX2_P: Module1.170 (HDMI0_TX2_P); also elsewhere on the board
/CM4/HDMI1.CEC: Module1.149 (HDMI1_CEC); also elsewhere on the board
/CM4/HDMI1.CLK_N: Module1.166 (HDMI1_CLK_N); also elsewhere on the board
/CM4/HDMI1.CLK_P: Module1.164 (HDMI1_CLK_P); also elsewhere on the board
/CM4/HDMI1.HOT: Module1.143 (HDMI1_HOTPLUG); also elsewhere on the board
/CM4/HDMI1.SCL: Module1.147 (HDMI1_SCL); also elsewhere on the board
/CM4/HDMI1.SDA: Module1.145 (HDMI1_SDA); also elsewhere on the board
/CM4/HDMI1.TX0_N: Module1.160 (HDMI1_TX0_N); also elsewhere on the board
/CM4/HDMI1.TX0_P: Module1.158 (HDMI1_TX0_P); also elsewhere on the board
/CM4/HDMI1.TX1_N: Module1.154 (HDMI1_TX1_N); also elsewhere on the board
/CM4/HDMI1.TX1_P: Module1.152 (HDMI1_TX1_P); also elsewhere on the board
/CM4/HDMI1.TX2_N: Module1.148 (HDMI1_TX2_N); also elsewhere on the board
/CM4/HDMI1.TX2_P: Module1.146 (HDMI1_TX2_P); also elsewhere on the board
/CM4/I2C.SCL: Module1.80 (SCL0); also elsewhere on the board
/CM4/I2C.SDA: Module1.82 (SDA0); also elsewhere on the board
/CM4/ID.SC: Module1.35 (ID_SC); also elsewhere on the board
/CM4/ID.SD: Module1.36 (ID_SD); also elsewhere on the board
/CM4/PCIe.CLK_N: Module1.112 (PCIe_CLK_N)
/CM4/PCIe.CLK_P: Module1.110 (PCIe_CLK_P)
/CM4/PCIe.CLK_nREQ: Module1.102 (PCIe_CLK_nREQ)
/CM4/PCIe.RX_N: Module1.118 (PCIe_RX_N)
/CM4/PCIe.RX_P: Module1.116 (PCIe_RX_P)
/CM4/PCIe.TX_N: Module1.124 (PCIe_TX_N)
/CM4/PCIe.TX_P: Module1.122 (PCIe_TX_P)
/CM4/PCIe.nRST: Module1.109 (PCIe_nRST)
/CM4/PI_nLED_Activity: Module1.21 (PI_nLED_Activity), R3.2
/CM4/RUN_PG: Module1.92 (RUN_PG)
/CM4/SD.CLK: Module1.57 (SD_CLK); also elsewhere on the board
/CM4/SD.CMD: Module1.62 (SD_CMD); also elsewhere on the board
/CM4/SD.DAT0: Module1.63 (SD_DAT0); also elsewhere on the board
/CM4/SD.DAT1: Module1.67 (SD_DAT1); also elsewhere on the board
/CM4/SD.DAT2: Module1.69 (SD_DAT2); also elsewhere on the board
/CM4/SD.DAT3: Module1.61 (SD_DAT3); also elsewhere on the board
/CM4/SD.DAT4: Module1.68 (SD_DAT4)
/CM4/SD.DAT5: Module1.64 (SD_DAT5)
/CM4/SD.DAT6: Module1.72 (SD_DAT6)
/CM4/SD.DAT7: Module1.70 (SD_DAT7)
/CM4/SD.VDD_OVER: Module1.73 (SD_VDD_Override)
/CM4/SD_reserved: Module1.76 (Reserved); also elsewhere on the board
/CM4/USB.N: Module1.103 (USB2_N); also elsewhere on the board
/CM4/USB.OTG: Module1.101 (USB_OTG_ID); also elsewhere on the board
/CM4/USB.P: Module1.105 (USB2_P); also elsewhere on the board
/CM4/VHEAD: J13.1; also elsewhere on the board
/CM4/WL_nDisable: J5.1, Module1.89 (WL_nDisable)
/CM4/nEXTRST: Module1.100 (nEXTRST); also elsewhere on the board
/CM4/nPWR_LED: Module1.95 (nPI_LED_PWR), U1.2
/CM4/nRPIBOOT: J3.1, Module1.93 (nRPIBOOT)
GND: J3.2, J5.2, J5.4, J13.2, Module1.1 (GND), Module1.2 (GND), Module1.7 (GND), Module1.8 (GND), Module1.13 (GND), Module1.14 (GND), Module1.22 (GND), Module1.23 (GND), Module1.32 (GND), Module1.33 (GND), Module1.42 (GND), Module1.43 (GND), Module1.52 (GND), Module1.53 (GND), Module1.59 (GND), Module1.60 (GND), Module1.65 (GND), Module1.66 (GND), Module1.71 (GND), Module1.74 (GND), Module1.75 (SD_PWR_ON), Module1.98 (GND), Module1.107 (GND), Module1.108 (GND), Module1.113 (GND), Module1.114 (GND), Module1.119 (GND), Module1.120 (GND), Module1.125 (GND), Module1.126 (GND), Module1.131 (GND), Module1.132 (GND), Module1.137 (GND), Module1.138 (GND), Module1.144 (GND), Module1.150 (GND), Module1.155 (GND), Module1.156 (GND), Module1.161 (GND), Module1.162 (GND), Module1.167 (GND), Module1.168 (GND), Module1.173 (GND), Module1.174 (GND), Module1.179 (GND), Module1.180 (GND), Module1.185 (GND), Module1.186 (GND), Module1.191 (GND), Module1.192 (GND), Module1.197 (GND), Module1.198 (GND), U1.3 (GND); also elsewhere on the board
unnamed: D1.1 (K), R3.1, TP1.1
unnamed: D2.1 (K), R4.1, TP2.1
unnamed: R4.2, U1.4

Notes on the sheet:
PWR LED
Activity LED

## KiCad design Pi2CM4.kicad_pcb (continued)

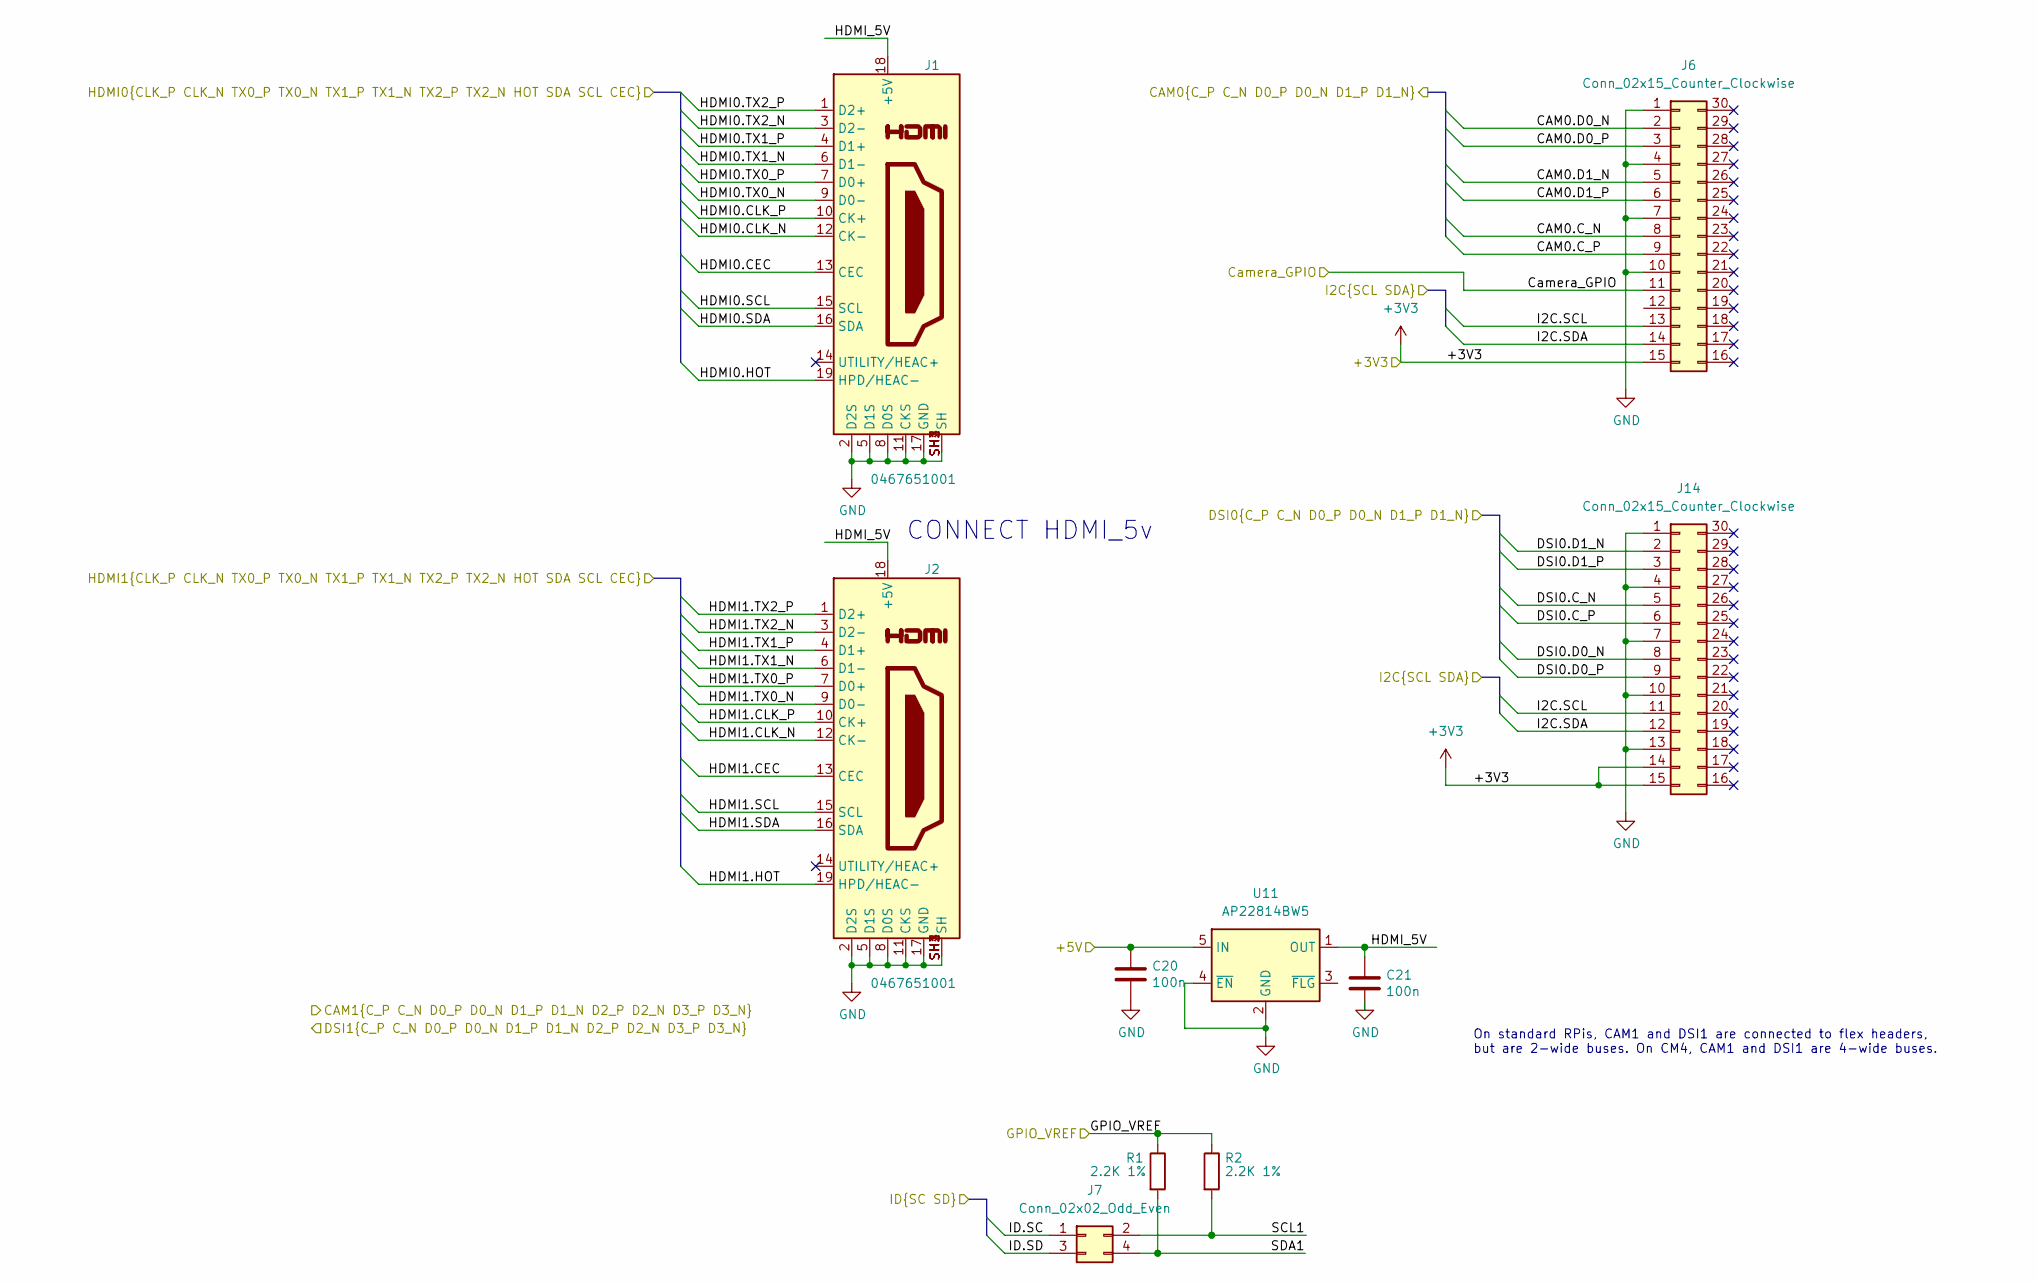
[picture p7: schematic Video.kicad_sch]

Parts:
C20, C21: 100n; C_0402_1005Metric; Part Description 0.1uF 10% 16V Ceramic Capacitor X7R 040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
J1, J2: 0467651001; HDMI_Micro-D_Molex_46765-1x01; Part Description HDMI Connector, Right Angle, 19 Contact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
J6, J14: Conn_02x15_Counter_Clockwise; Molex_052610-1572_2x15-1MP_P1.0mm_Vertical
J7: Conn_02x02_Odd_Even; PinSocket_2x02_P2.54mm_Vertical
R1, R2: 2.2K 1%; R_0402_1005Metric; Part Description Resistor 2.2K M1005 1% 63mW
U11: AP22814BW5; SOT-23-5

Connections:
+3V3: J6.15, J14.14, J14.15; also elsewhere on the board
+5V: C20.1, U11.5 (IN); also elsewhere on the board
/CM4/CAM0.C_N: J6.8; also elsewhere on the board
/CM4/CAM0.C_P: J6.9; also elsewhere on the board
/CM4/CAM0.D0_N: J6.2; also elsewhere on the board
/CM4/CAM0.D0_P: J6.3; also elsewhere on the board
/CM4/CAM0.D1_N: J6.5; also elsewhere on the board
/CM4/CAM0.D1_P: J6.6; also elsewhere on the board
/CM4/Camera_GPIO: J6.11; also elsewhere on the board
/CM4/DSI0.C_N: J14.5; also elsewhere on the board
/CM4/DSI0.C_P: J14.6; also elsewhere on the board
/CM4/DSI0.D0_N: J14.8; also elsewhere on the board
/CM4/DSI0.D0_P: J14.9; also elsewhere on the board
/CM4/DSI0.D1_N: J14.2; also elsewhere on the board
/CM4/DSI0.D1_P: J14.3; also elsewhere on the board
/CM4/GPIO_VREF: R1.1, R2.1; also elsewhere on the board
/CM4/HDMI0.CEC: J1.13 (CEC); also elsewhere on the board
/CM4/HDMI0.CLK_N: J1.12 (CK-); also elsewhere on the board
/CM4/HDMI0.CLK_P: J1.10 (CK+); also elsewhere on the board
/CM4/HDMI0.HOT: J1.19 (HPD/HEAC-); also elsewhere on the board
/CM4/HDMI0.SCL: J1.15 (SCL); also elsewhere on the board
/CM4/HDMI0.SDA: J1.16 (SDA); also elsewhere on the board
/CM4/HDMI0.TX0_N: J1.9 (D0-); also elsewhere on the board
/CM4/HDMI0.TX0_P: J1.7 (D0+); also elsewhere on the board
/CM4/HDMI0.TX1_N: J1.6 (D1-); also elsewhere on the board
/CM4/HDMI0.TX1_P: J1.4 (D1+); also elsewhere on the board
/CM4/HDMI0.TX2_N: J1.3 (D2-); also elsewhere on the board
/CM4/HDMI0.TX2_P: J1.1 (D2+); also elsewhere on the board
/CM4/HDMI1.CEC: J2.13 (CEC); also elsewhere on the board
/CM4/HDMI1.CLK_N: J2.12 (CK-); also elsewhere on the board
/CM4/HDMI1.CLK_P: J2.10 (CK+); also elsewhere on the board
/CM4/HDMI1.HOT: J2.19 (HPD/HEAC-); also elsewhere on the board
/CM4/HDMI1.SCL: J2.15 (SCL); also elsewhere on the board
/CM4/HDMI1.SDA: J2.16 (SDA); also elsewhere on the board
/CM4/HDMI1.TX0_N: J2.9 (D0-); also elsewhere on the board
/CM4/HDMI1.TX0_P: J2.7 (D0+); also elsewhere on the board
/CM4/HDMI1.TX1_N: J2.6 (D1-); also elsewhere on the board
/CM4/HDMI1.TX1_P: J2.4 (D1+); also elsewhere on the board
/CM4/HDMI1.TX2_N: J2.3 (D2-); also elsewhere on the board
/CM4/HDMI1.TX2_P: J2.1 (D2+); also elsewhere on the board
/CM4/I2C.SCL: J6.13, J14.11; also elsewhere on the board
/CM4/I2C.SDA: J6.14, J14.12; also elsewhere on the board
/CM4/ID.SC: J7.1; also elsewhere on the board
/CM4/ID.SD: J7.3; also elsewhere on the board
/Video/HDMI_5V: C21.1, J1.18 (+5V), J2.18 (+5V), U11.1 (OUT)
/Video/SCL1: J7.2, R2.2
/Video/SDA1: J7.4, R1.2
GND: C20.2, C21.2, J1.2 (D2S), J1.5 (D1S), J1.8 (D0S), J1.11 (CKS), J1.17 (GND), J1.SH1 (SH), J1.SH2 (SH), J1.SH3 (SH), J1.SH4 (SH), J2.2 (D2S), J2.5 (D1S), J2.8 (D0S), J2.11 (CKS), J2.17 (GND), J2.SH1 (SH), J2.SH2 (SH), J2.SH3 (SH), J2.SH4 (SH), J6.1, J6.4, J6.7, J6.10, J14.1, J14.4, J14.7, J14.10, J14.13, U11.2 (GND), U11.4 (~EN); also elsewhere on the board

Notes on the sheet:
CONNECT HDMI_5v
On standard RPis, CAM1 and DSI1 are connected to flex headers, but are 2-wide buses. On CM4, CAM1 and DSI1 are 4-wide buses.

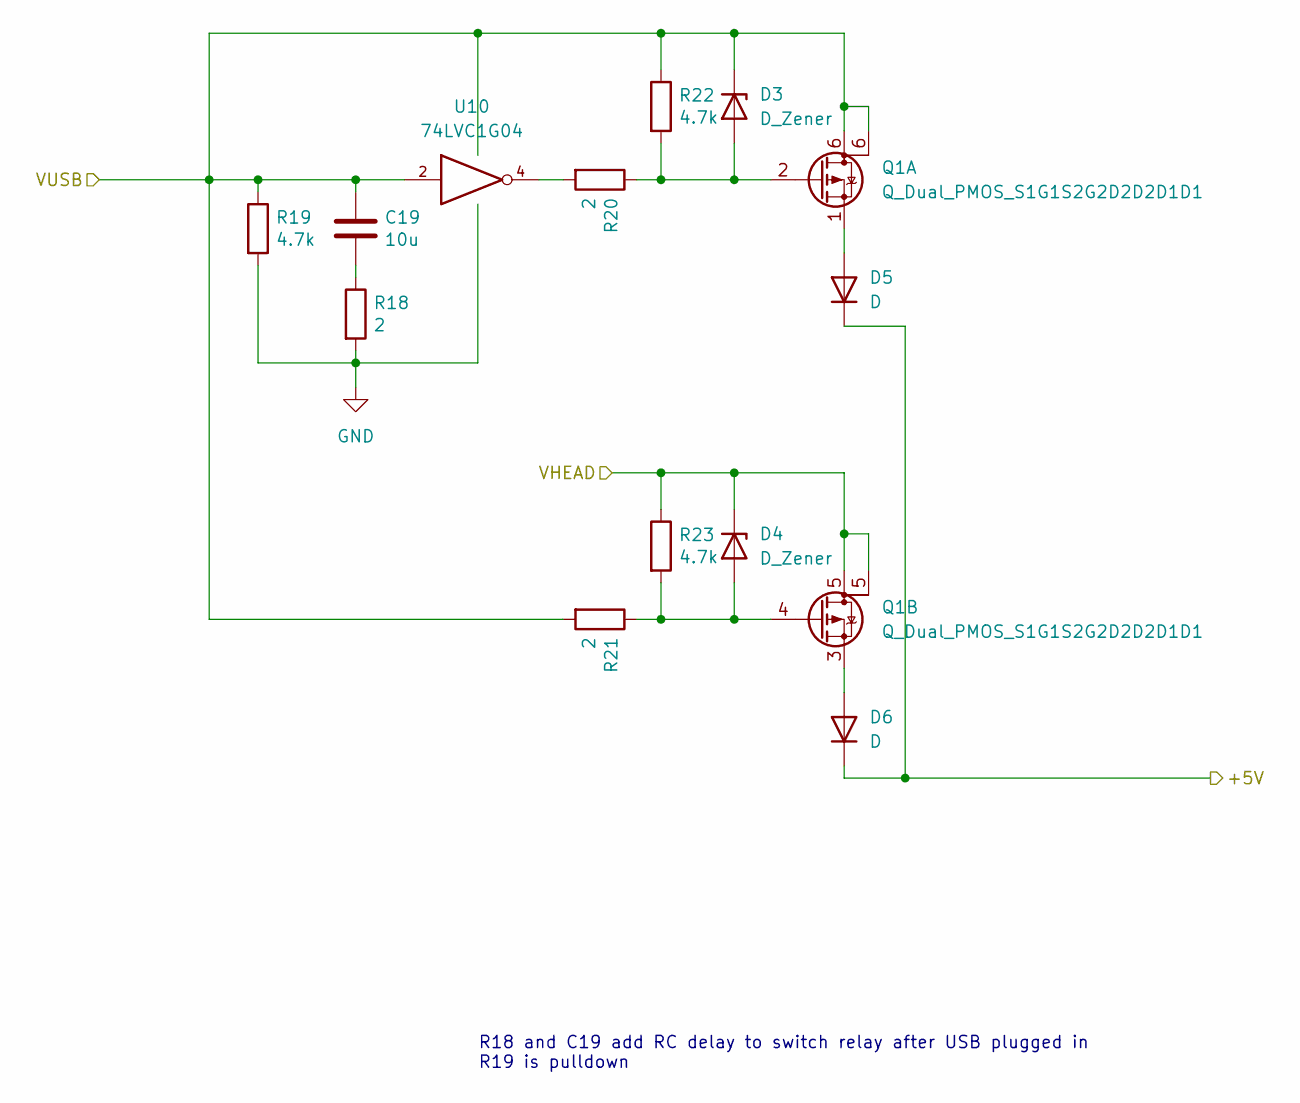
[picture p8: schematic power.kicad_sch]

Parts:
C19: 10u; C_0805_2012Metric; Part Description 10uF 10% 10V Ceramic Capacitor X7R 0805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
D3, D4: D_Zener; D_SOD-123
D5, D6: D; D_MELF
Q1: Q_Dual_PMOS_S1G1S2G2D2D2D1D1; PowerPAK_1212_Dual
R18, R20, R21: 2; R_2010_5025Metric; Part Description Resistor 1K M1005 1% 63mW
R19, R22, R23: 4.7k; R_0402_1005Metric; Part Description Resistor 1K M1005 1% 63mW
U10: 74LVC1G04; SOT-23-5

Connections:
+5V: D5.1 (K), D6.1 (K); also elsewhere on the board
/CM4/VHEAD: D4.1 (K), Q1.5 (D), R23.1; also elsewhere on the board
GND: R18.2, R19.2, U10.3 (GND); also elsewhere on the board
unnamed: C19.2, R18.1
unnamed: D3.2 (A), Q1.2 (G), R20.1, R22.2
unnamed: D4.2 (A), Q1.4 (G), R21.1, R23.2
unnamed: D5.2 (A), Q1.1 (S)
unnamed: D6.2 (A), Q1.3 (S)
unnamed: R20.2, U10.4
VCC: C19.1, D3.1 (K), Q1.6 (G), R19.1, R21.2, R22.1, U10.2, U10.5 (VCC)

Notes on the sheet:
R18 and C19 add RC delay to switch relay after USB plugged in R19 is pulldown

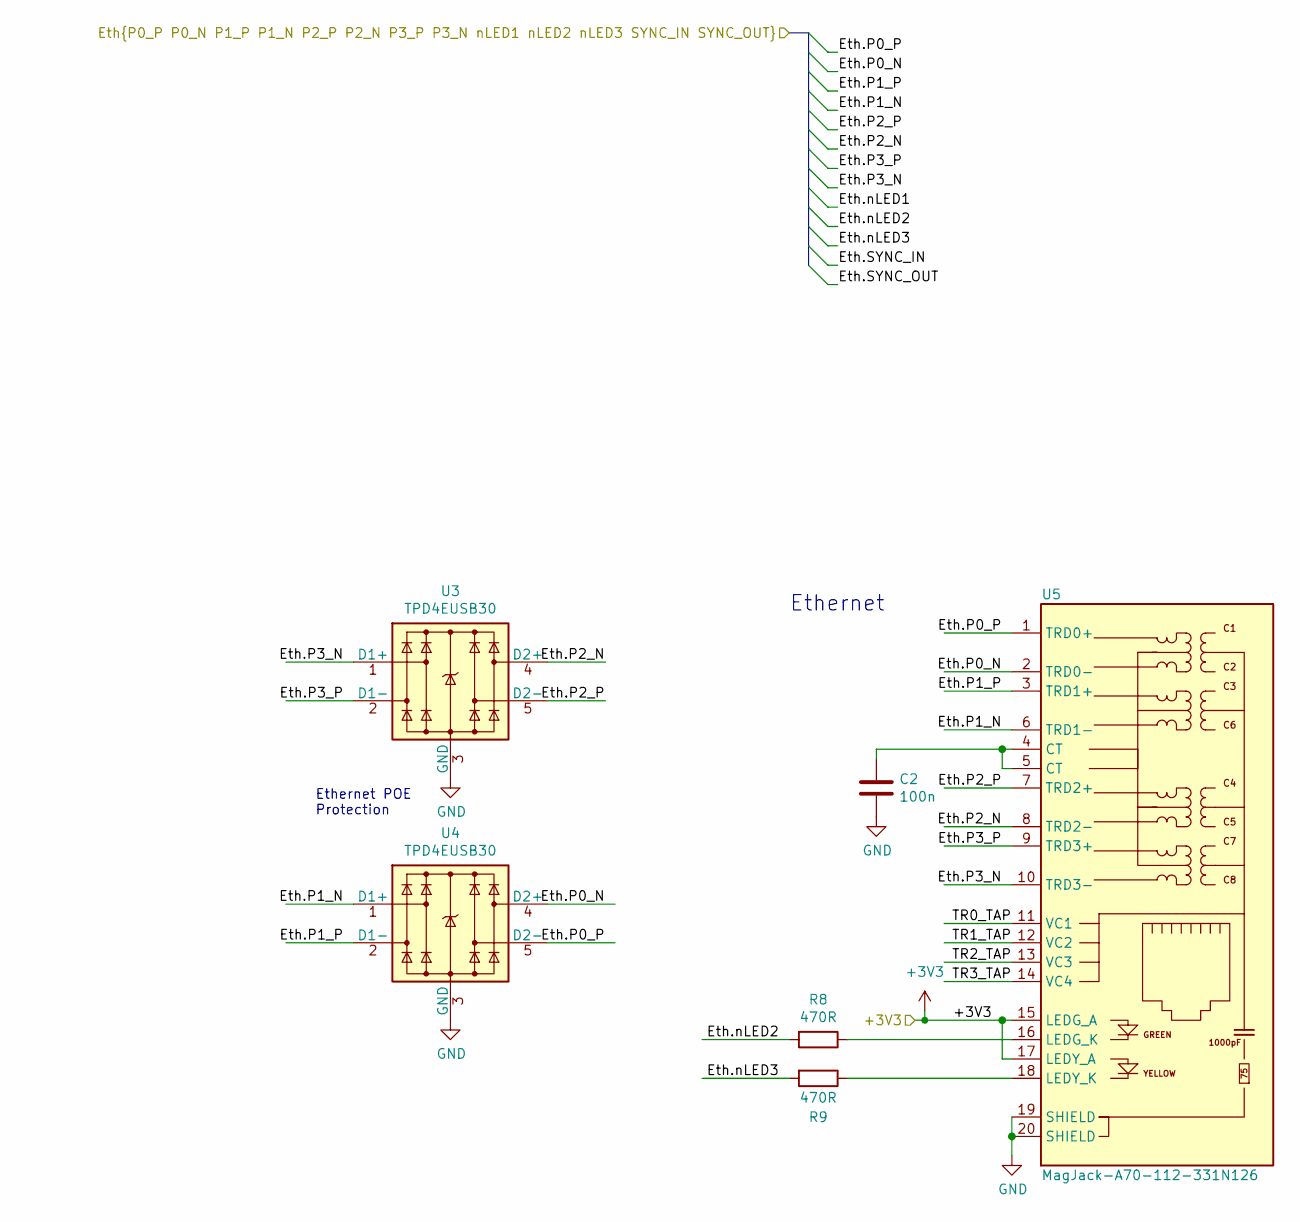
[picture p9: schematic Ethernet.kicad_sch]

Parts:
C2: 100n; C_0402_1005Metric; Part Description 0.1uF 10% 16V Ceramic Capacitor X7R 040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
R8, R9: 470R; R_0402_1005Metric; Part Description Resistor 470R M1005 1% 63mW
U3, U4: TPD4EUSB30; USON-10_2.5x1.0mm_P0.5mm; Part Description Quad TVS diode for high speed signals (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
U5: MagJack-A70-112-331N126; TRJG0926HENL; Part Description Gigabit Ethernet Magjack

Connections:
+3V3: U5.15 (LEDG_A), U5.17 (LEDY_A); also elsewhere on the board
/CM4/Eth.P0_N: U4.4 (D2+), U4.7, U5.2 (TRD0-); also elsewhere on the board
/CM4/Eth.P0_P: U4.5 (D2-), U4.6, U5.1 (TRD0+); also elsewhere on the board
/CM4/Eth.P1_N: U4.1 (D1+), U4.10, U5.6 (TRD1-); also elsewhere on the board
/CM4/Eth.P1_P: U4.2 (D1-), U4.9, U5.3 (TRD1+); also elsewhere on the board
/CM4/Eth.P2_N: U3.4 (D2+), U3.7, U5.8 (TRD2-); also elsewhere on the board
/CM4/Eth.P2_P: U3.5 (D2-), U3.6, U5.7 (TRD2+); also elsewhere on the board
/CM4/Eth.P3_N: U3.1 (D1+), U3.10, U5.10 (TRD3-); also elsewhere on the board
/CM4/Eth.P3_P: U3.2 (D1-), U3.9, U5.9 (TRD3+); also elsewhere on the board
/CM4/Eth.nLED2: R8.2; also elsewhere on the board
/CM4/Eth.nLED3: R9.2; also elsewhere on the board
/Ethernet/TR0_TAP: U5.11 (VC1)
/Ethernet/TR1_TAP: U5.12 (VC2)
/Ethernet/TR2_TAP: U5.13 (VC3)
/Ethernet/TR3_TAP: U5.14 (VC4)
GND: C2.2, U3.3 (GND), U3.8 (GND), U4.3 (GND), U4.8 (GND), U5.19 (SHIELD), U5.20 (SHIELD); also elsewhere on the board
unnamed: C2.1, U5.4 (CT), U5.5 (CT)
unnamed: R8.1, U5.16 (LEDG_K)
unnamed: R9.1, U5.18 (LEDY_K)

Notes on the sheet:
Ethernet
Ethernet POE Protection

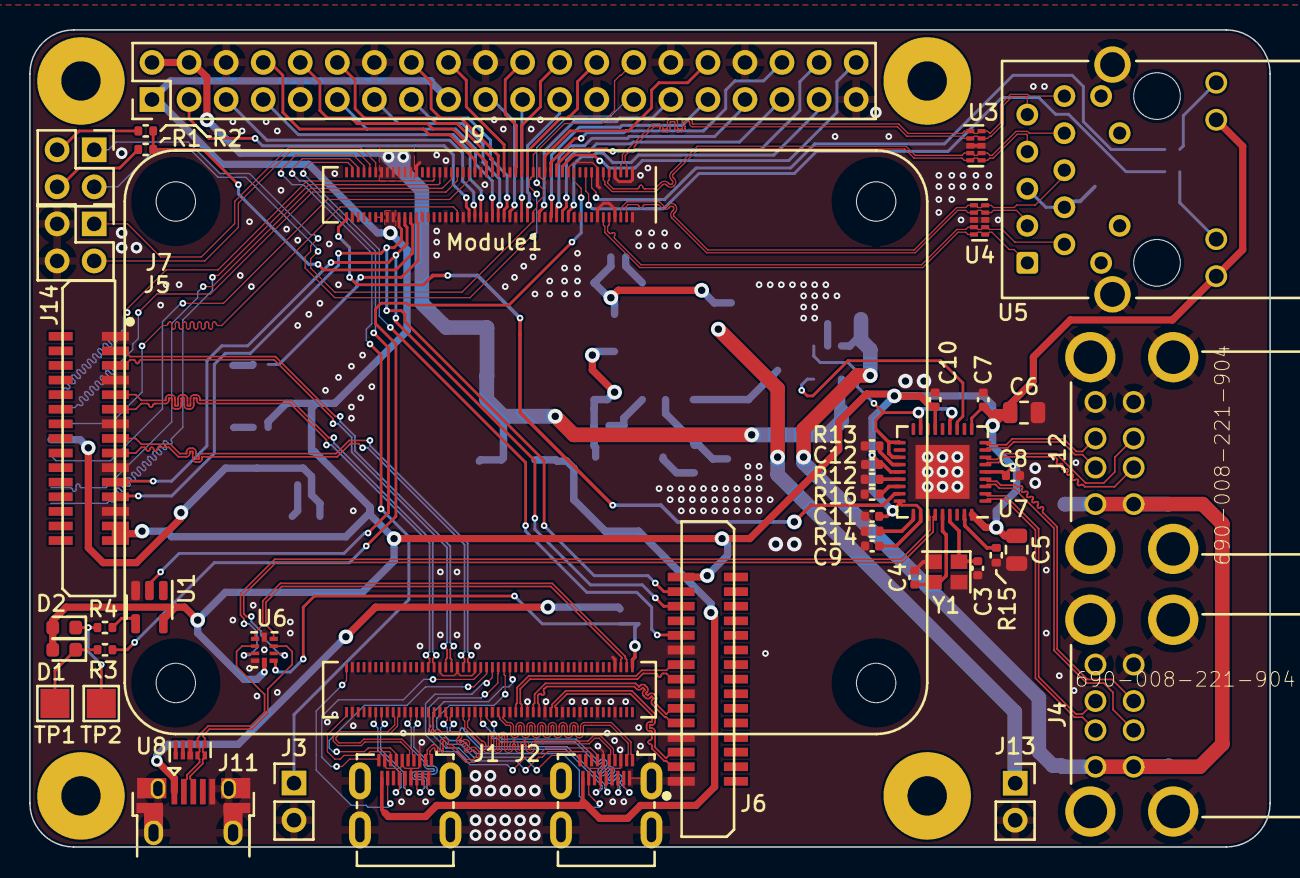
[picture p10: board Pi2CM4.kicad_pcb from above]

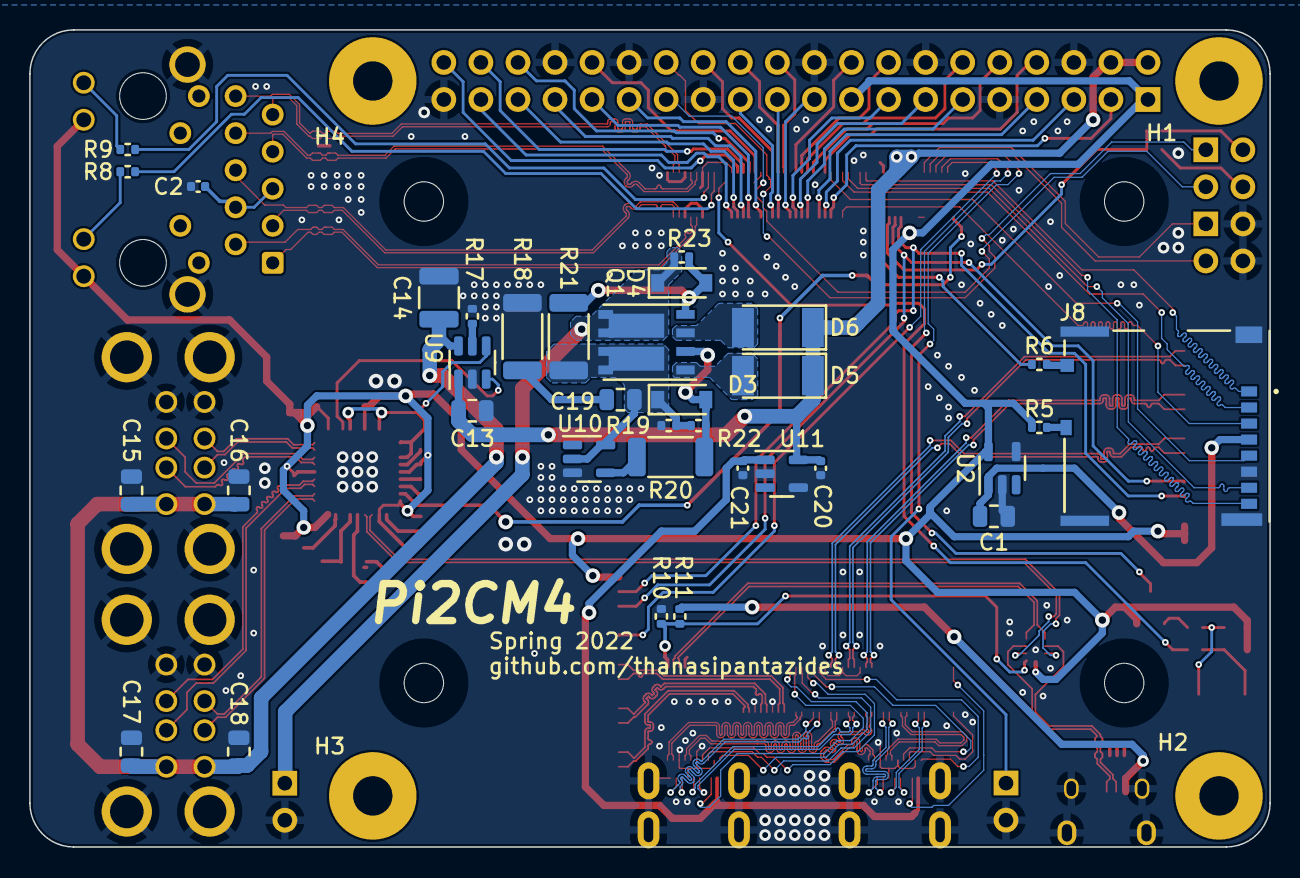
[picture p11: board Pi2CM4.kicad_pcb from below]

Board: 4 copper layers, 85.0 x 56.0 mm, 82 parts (34 on the bottom side), 144 nets.
